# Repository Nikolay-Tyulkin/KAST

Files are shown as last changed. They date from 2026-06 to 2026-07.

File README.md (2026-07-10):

# KAST

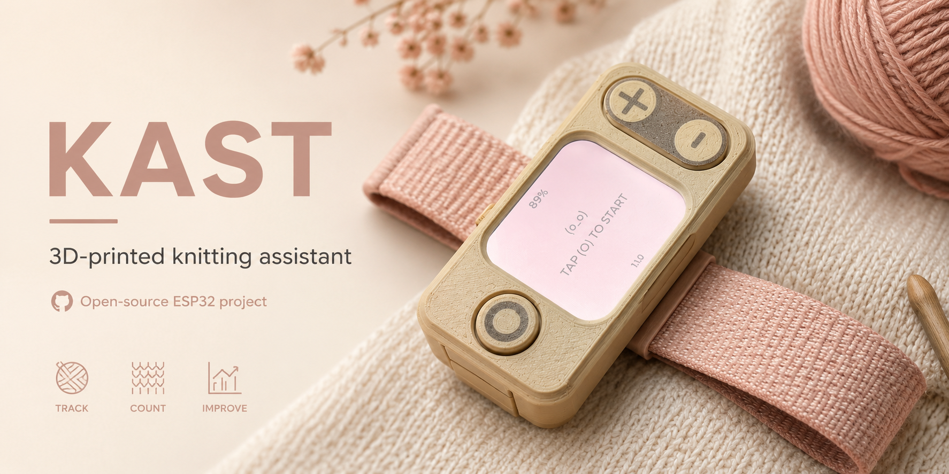
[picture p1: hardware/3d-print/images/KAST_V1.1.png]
KAST render


KAST is a portable knitting assistant based on the
`Waveshare ESP32-S3-LCD-1.69` board. The device counts rows, shows battery
charge as a percentage, and is controlled by three external buttons.

## Status

The repository currently contains an ESP-IDF MVP firmware:

- row counting with `+` and `-` buttons;
- Wi-Fi settings portal for boot beep, screen brightness, and screen sleep;
- a universal button for start, pause, resume, reset, and secondary actions;
- confirmed row reset flow;
- a display with a large row counter, session status, battery percentage, and firmware version;
- session, statistics, and history persistence in NVS;
- enclosure, 22 mm strap attachment, assembly, and 3D printing materials in `hardware/`.

The project is built with ESP-IDF CLI. Arduino and PlatformIO are not used.

## Video Demonstration

KAST Demonstration (https://www.youtube.com/shorts/3yuL7Apywl4)

## Quick Start

Open PowerShell 5.1 in the project root and activate the ESP-IDF profile:

```powershell
. "C:\Espressif\tools\Microsoft.v6.0.1.PowerShell_profile.ps1"
```

Build the firmware:

```powershell
idf.py build
```

Flash the current board on `COM14`:

```powershell
idf.py -p COM14 build flash
```

Open the device monitor:

```powershell
idf.py -p COM14 monitor
```

Exit the monitor with `Ctrl+]`.

## Firmware Version

The version is set in the root [`CMakeLists.txt`](CMakeLists.txt) through
`PROJECT_VER`, for example:

```cmake
set(PROJECT_VER "0.0.1-dev.37")
```

This value is passed into the firmware as `APP_VERSION`, shown at the bottom of
the screen, and included in ESP-IDF `Application information`. Before flashing a
working board, increment the dev counter by `1` so the running build is visible
on the screen.

## Controls

The confirmed external buttons are connected between GPIO and `GND`; pressed
state is active low (`0`).

| Button | GPIO | Purpose |
| --- | --- | --- |
| `+` | `GPIO2` | Add one row |
| `-` | `GPIO16` | Remove one row |
| Universal | `GPIO17` | Start, pause, resume, reset, and secondary actions |

Row reset sequence: `3` short presses of the universal button, then `1` long
press within a `2 s` window, then confirmation with one short press within
`5 s`.

Hold `+` for `3 s` in the main screen to toggle the settings Wi-Fi AP. When AP
is enabled, the device screen shows `SETTINGS` and a QR code for joining the
settings Wi-Fi network.

## Settings Portal

The device can expose a local Wi-Fi settings page without an external router.

- AP SSID: `KAST Settings`.
- Manual URL: `http://192.168.4.1`.
- The device settings screen shows a QR code for connecting to the settings AP.
- Captive portal DNS tries to open the settings page automatically after joining
  the AP; if the OS does not open it, use the manual URL.
- Settings are applied after `Save` and persisted in NVS.
- Available settings: boot beep on/off, screen brightness `0..100`, screen sleep
  on/off, and time until screen dimming.
- Current rows are saved after every row change and restored after power off/on.

## Hardware

Key board and wiring facts:

- board: `Waveshare ESP32-S3-LCD-1.69`;
- LCD: `SCLK=GPIO6`, `MOSI=GPIO7`, `RST=GPIO8`, `DC=GPIO4`, `CS=GPIO5`, `BL=GPIO15`;
- power latch: `SYS_OUT=GPIO40`, `SYS_EN=GPIO41`;
- battery ADC: `GPIO1`, which is `ADC_UNIT_1` / `ADC_CHANNEL_0` in ESP-IDF;
- battery divider: `R3=200k`, `R7=100k`, voltage multiplier `3`;
- primary strap: standard 22 mm purchased band with a 3D-printed holder.

Hardware documentation:

| Document | Contents |
| --- | --- |
| [`hardware/README.md`](hardware/README.md) | Hardware section index |
| [`hardware/BOM.md`](hardware/BOM.md) | Bill of materials |
| [`hardware/ASSEMBLY.md`](hardware/ASSEMBLY.md) | Assembly and smoke check |
| [`hardware/REVISIONS.md`](hardware/REVISIONS.md) | Hardware revision log |
| [`hardware/3d-print/README.md`](hardware/3d-print/README.md) | Enclosure, 3D printing, and model files |
| [Thingiverse](https://www.thingiverse.com/thing:7372245) | 3D-printable enclosure on Thingiverse |

## Project Structure

| Path | Purpose |
| --- | --- |
| [`main/main.c`](main/main.c) | Main firmware logic and UI |
| [`main/idf_component.yml`](main/idf_component.yml) | ESP-IDF managed dependencies |
| [`sdkconfig.defaults`](sdkconfig.defaults) | Base ESP-IDF settings |
| [`PROJECT_SPEC.md`](PROJECT_SPEC.md) | Product specification |
| [`IMPLEMENTATION_PLAN.md`](IMPLEMENTATION_PLAN.md) | Implementation plan |
| [`ACCEPTANCE_CRITERIA.md`](ACCEPTANCE_CRITERIA.md) | Acceptance criteria |
| [`hardware/`](hardware/README.md) | Hardware, enclosure, and assembly |

## Verification After Changes

Minimal local firmware check:

```powershell
idf.py build
```

After flashing the device, verify:

- the screen turns on;
- the expected `0.0.1-dev.N` version is visible at the bottom;
- `+` and `-` change the row counter;
- the battery is displayed as a percentage.

For battery diagnostics, look for monitor lines in this format:

```text
Battery ADC raw=... adc_mv=... bat_mv=... pct=...
```

## Development Notes

- ESP-IDF target: `esp32s3`.
- UI and logic term: `rows`.
- Activate the ESP-IDF PowerShell profile with the dot-sourcing command from
  "Quick Start".
- `source ...` does not activate the profile in the current PowerShell 5.1
  session.

## License

- Firmware and repository documentation: [`MIT License`](LICENSE).
- 3D printed parts, CAD files, and physical-design assets:
  [`CC BY-NC 4.0`](hardware/3d-print/LICENSE.md).

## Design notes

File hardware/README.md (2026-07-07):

# Hardware

This section contains the physical-device materials for KAST: enclosure files,
3D-printing assets, assembly photos, strap options, and component notes.

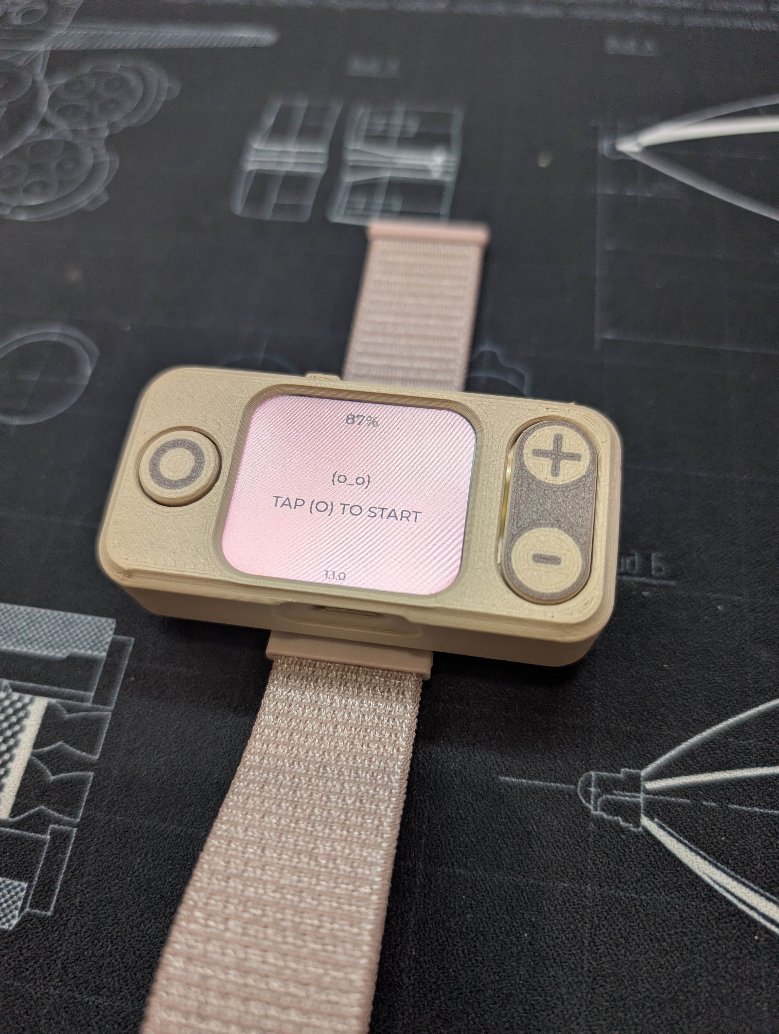
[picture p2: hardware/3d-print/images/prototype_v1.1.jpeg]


## Sections

| Path | Purpose |
| --- | --- |
| [`3d-print/`](3d-print/README.md) | Enclosure files, print settings, and assembly-oriented 3D-print notes |
| [`3d-print/source/`](3d-print/source/README.md) | Source STEP files for the assembly, enclosure, and components |
| [`BOM.md`](BOM.md) | Bill of materials for the build |
| [`ASSEMBLY.md`](ASSEMBLY.md) | Assembly steps and smoke check |
| [`REVISIONS.md`](REVISIONS.md) | Hardware revision log |
| [`3d-print/LICENSE.md`](3d-print/LICENSE.md) | License for 3D printed parts and CAD files |

## Target Device

- Board: `Waveshare ESP32-S3-LCD-1.69`
- Screen: integrated board LCD
- Controls: 3 external buttons
- Power: battery connected to the board
- Strap: standard 22 mm purchased band
- Main use case: row counting while knitting

## License

The 3D printed parts, CAD files, and physical-design assets are licensed under
[`CC BY-NC 4.0`](3d-print/LICENSE.md).

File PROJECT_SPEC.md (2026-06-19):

# PROJECT_SPEC: KAST

## 1. Product Goal

KAST is a standalone knitting assistant based on the
`Waveshare ESP32-S3-LCD-1.69` board. It helps the user count rows reliably
during knitting, control the current session, and see battery state.

The MVP goal is to replace a manual row counter with a simple gift-ready device
that requires no training, runs from battery power, and keeps local history for
completed sessions.

Core value:

- the user sees a large current row count;
- the user can quickly add or remove one row with physical buttons;
- the user can start, pause, finish, and inspect basic statistics;
- the device warns about low battery;
- on shutdown, the current session is closed and saved to history.

## 2. MVP Scope

Included in MVP:

- display current row count;
- manual row counter control with `+` and `-` buttons;
- universal button for session control, reset confirmation, and statistics;
- built-in board power button for power on/off;
- confirmation before row reset;
- battery percentage display;
- low-battery warning;
- current session timer in `hh:mm:ss`;
- current session status display;
- firmware version shown at the bottom of the screen;
- current session closure on shutdown or finish;
- completed session storage in local NVS history;
- firmware for `Waveshare ESP32-S3-LCD-1.69` built with ESP-IDF.

The MVP is designed around one current active session. After power-on, a new
session does not start automatically; the user must explicitly start it with the
universal button.

Out of scope for MVP:

- BLE, Wi-Fi, mobile app, web UI, cloud sync, OTA updates;
- project lists, user profiles, pattern templates, complex analytics;
- automatic row detection without a button press;
- multiple independent row counters;
- Arduino and PlatformIO builds.

## 3. Target Users

Primary user:

- a person who knits by hand and wants to avoid losing row count;
- a non-technical user;
- a user who may receive the device as a gift and expects understandable
  behavior without setup.

Secondary users:

- the gift giver, who wants a ready-to-use device;
- the developer or assembler, who flashes and checks the device before handoff.

UX requirements:

- minimal modes;
- large digits;
- clear physical actions;
- protection from accidental reset;
- no phone or computer required for normal use.

## 4. User Scenarios

### 4.1 Power On

1. The user presses the board power button.
2. The device turns on and holds power through the latch.
3. The screen shows the no-active-session state.
4. Battery percentage is visible in the top-right area.
5. Firmware version is visible at the bottom.

Expected result: the user understands that the device is ready, but no session
has started yet.

### 4.2 Start New Session

1. The user short-presses the universal button.
2. The device creates a new session.
3. Row count is set to `0`.
4. Session timer starts from `00:00:00`.
5. Status changes to active.

Expected result: the user can start knitting and count rows.

### 4.3 Add Row

1. The user completes a knitting row.
2. The user presses `+`.
3. Row count increases by `1`.
4. The updated number is shown immediately in the center of the screen.

Expected result: each completed row is recorded with one press.

### 4.4 Correct Counting Error

1. The user notices that one extra row was counted.
2. The user presses `-`.
3. If row count is greater than `0`, it decreases by `1`.
4. If row count is `0`, it remains `0`.

Expected result: the user can correct mistakes without creating negative values.

### 4.5 Pause and Resume

1. During an active session, the user short-presses the universal button.
2. The device pauses the session.
3. The clean session timer stops.
4. The screen shows paused status.
5. Another short universal-button press resumes the session.

Expected result: break time is not included in active knitting duration.

### 4.6 Reset Rows With Confirmation

1. The user initiates reset with `3` short universal-button presses followed by
   `1` long universal-button press within a `2 s` window.
2. The device shows a reset confirmation prompt.
3. The device waits up to `5 s` for confirmation.
4. The user confirms with one short universal-button press.
5. Row count becomes `0`.
6. If confirmation does not happen within `5 s`, reset is canceled.

Expected result: accidental presses do not erase the current row count.

### 4.7 Finish Session

1. The user finishes the current knitting work.
2. The user performs one long universal-button press.
3. The device saves the session to history.
4. The saved record includes start time, end time, duration, and final row count
   where available.
5. The screen returns to no-active-session state.

Expected result: current work is saved to history and the next session starts
separately.

### 4.8 Power Off

1. The user turns off the device with the board power button.
2. If a session is active or paused, the device closes and saves it.
3. The device drops the power latch.

Expected result: the closed session does not resume automatically on next
power-on.

### 4.9 View Statistics

1. The user holds `-` and the universal button together.
2. The device shows basic data from the last session and/or history.
3. The user can return to the main screen.

Expected result: the user can inspect previous work without external devices.

## 5. Functional Requirements

### 5.1 Display

- FR-001. The display shows the current row count as the most prominent element.
- FR-002. Battery percentage is visible in the top-right area.
- FR-003. The session timer is shown in `hh:mm:ss`.
- FR-004. The current status is visible: no session, active, paused, reset
  confirmation, low battery, or saved.
- FR-005. Firmware version is visible at the bottom of the screen.
- FR-006. The UI must remain readable on the `240x280` display.

### 5.2 Row Counter

- FR-010. In an active session, `+` increments row count by `1`.
- FR-011. In an active session, `-` decrements row count by `1`.
- FR-012. Row count never goes below `0`.
- FR-013. Row count changes are shown within `200 ms` after a valid press.
- FR-014. `+` and `-` do not change rows while the session is paused.
- FR-015. Without an active session, `+` and `-` do not change rows, except for
  valid statistics combinations.

### 5.3 Session Management

- FR-020. A short universal-button press starts a session when no session is
  active.
- FR-021. A short universal-button press pauses an active session.
- FR-022. A short universal-button press resumes a paused session.
- FR-023. A long universal-button press (`1.5 s`) finishes an active or paused
  session and saves it.
- FR-024. A session has a clean active timer that excludes pause time.
- FR-025. Only one session can be active at a time.

### 5.4 Row Reset

- FR-030. Reset requires `3` short universal-button presses followed by `1` long
  press within a `2 s` window.
- FR-031. Reset opens a confirmation prompt.
- FR-032. Confirmation requires one short universal-button press within `5 s`.
- FR-033. Unconfirmed reset is canceled and row count remains unchanged.

### 5.5 Battery and Power

- FR-040. Battery is measured through `GPIO1` / `ADC_CHANNEL_0`.
- FR-041. Battery voltage is calculated from ADC voltage using multiplier `3`.
- FR-042. Battery percentage is displayed.
- FR-043. `pct < 15` shows a low-battery warning.
- FR-044. On normal power-off, an active or paused session is saved before
  `SYS_EN` is set to `0`.

### 5.6 History and Statistics

- FR-050. Completed sessions are stored locally in NVS.
- FR-051. MVP history stores the latest `20` completed sessions.
- FR-052. Statistics show last session, total rows, and total clean time.
- FR-053. History write happens on finish or normal shutdown, not on every row.
- FR-054. Empty or unreadable history does not block device startup.

### 5.7 Firmware Version

- FR-060. Firmware version is set with `PROJECT_VER` in the root
  `CMakeLists.txt`.
- FR-061. Version format is `0.0.1-dev.N`.
- FR-062. `PROJECT_VER` is passed to the firmware as `APP_VERSION`.
- FR-063. The version is visible on screen and in ESP-IDF application metadata.

## 6. Non-Functional Requirements

- NFR-001. Firmware builds with ESP-IDF CLI using `idf.py build`.
- NFR-002. Target is `esp32s3`.
- NFR-003. Normal flashing uses `idf.py -p COM14 build flash`.
- NFR-004. The device works without network connectivity.
- NFR-005. The UI is readable on the built-in round-corner LCD.
- NFR-006. Button handling includes debounce.
- NFR-007. Storage writes are limited to avoid unnecessary flash wear.
- NFR-008. Battery readings are diagnostic-friendly through monitor logs.
- NFR-009. Documentation covers buttons, build, flashing, and basic diagnostics.

## 7. Data Model

### 7.1 Session

Fields:

- `id` - session identifier;
- `state` - none, active, paused, finished;
- `rows_count` - current or final row count;
- `started_at` - session start timestamp or uptime;
- `ended_at` - finish timestamp or uptime;
- `active_duration_sec` - clean active duration excluding pause time;
- `pause_started_at` - current pause start time, if paused;
- `close_reason` - `finished`, `power_off`, or equivalent.

### 7.2 SessionHistory

Fields:

- `sessions` - saved session list;
- `max_sessions` - maximum saved sessions in MVP (`20`);
- `last_session_id` - reference to the latest completed session.

### 7.3 BatteryState

Fields:

- `raw_adc` - raw ADC value;
- `adc_mv` - voltage at the ADC pin;
- `battery_mv` - calculated battery voltage;
- `percent` - calculated charge percentage;
- `is_low` - low-battery flag;
- `updated_at` - last measurement time.

### 7.4 DeviceState

Fields:

- `firmware_version` - firmware version;
- `power_state` - on or shutting down;
- `screen_state` - main, reset confirmation, statistics, warning;
- `active_session_id` - current session if present.

### 7.5 InputEvent

Fields:

- `button` - `plus`, `minus`, `universal`, `power`;
- `event_type` - short press, long press, sequence, combination;
- `timestamp` - event time;
- `handled` - handled or rejected.

## 8. Technical Stack

Platform:

- `Waveshare ESP32-S3-LCD-1.69`;
- `ESP32-S3` microcontroller;
- `240x280` ST7789 LCD;
- physical `+`, `-`, universal, and board power buttons;
- battery measurement through `BAT_ADC` on `GPIO1`.

Firmware:

- ESP-IDF CLI;
- target `esp32s3`;
- C;
- FreeRTOS;
- LVGL through `esp_lvgl_port`;
- `esp_lcd` for display;
- `adc_oneshot` for battery;
- NVS for local history.

Confirmed local environment:

- ESP-IDF `v6.0.1`;
- `IDF_PATH`: `C:\esp\v6.0.1\esp-idf`;
- `IDF_TOOLS_PATH`: `C:\Espressif\tools`;
- PowerShell profile:
  `. "C:\Espressif\tools\Microsoft.v6.0.1.PowerShell_profile.ps1"`.

Commands:

- build: `idf.py build`;
- flash current board: `idf.py -p COM14 build flash`;
- monitor: `idf.py -p COM14 monitor`;
- exit monitor: `Ctrl+]`.

Battery:

- `BAT_ADC` is connected to `GPIO1`;
- ESP-IDF channel for ESP32-S3 is `ADC_CHANNEL_0`;
- divider is `R3=200k`, `R7=100k`;
- battery voltage multiplier is `3`.

## 9. Risks and Open Questions

### 9.1 Risks

- R-001. The universal button can become overloaded if too many gestures are
  added.
- R-002. Users may accidentally finish a session if long-press behavior is not
  obvious.
- R-003. Battery percentage may be approximate without calibration.
- R-004. Frequent flash writes can wear NVS if row changes are persisted too
  often.
- R-005. Small text or poor color settings can hurt readability.
- R-006. Sudden power loss can lose an active session if no checkpoint exists.
- R-007. Gift-device use requires very simple behavior; complex modes reduce
  clarity.

### 9.2 Open Questions

- Q-001. Should long-press finish require an additional confirmation?
- Q-002. Is `1.5 s` the final long-press threshold?
- Q-003. Is `15%` the final low-battery threshold?
- Q-004. Should session duration exclude all pause time? MVP says yes.
- Q-005. Is `20` completed sessions enough for MVP history?
- Q-006. Should statistics show only the last session or aggregated totals too?
- Q-007. Should row changes be allowed while paused? MVP says no.
- Q-008. What exact text should appear on the no-active-session screen?

## 10. MVP Acceptance Criteria

- AC-001. Firmware version is displayed in `0.0.1-dev.N` format.
- AC-002. After power-on, no session starts automatically.
- AC-003. The user can start a session with one short universal-button press.
- AC-004. In an active session, `+` increments rows by `1`.
- AC-005. In an active session, `-` decrements rows by `1`, but not below `0`.
- AC-006. Row count is displayed large in the center of the screen.
- AC-007. Battery is displayed as a percentage in the top-right area.
- AC-008. Session timer is displayed in `hh:mm:ss`.
- AC-009. Reset requires the specified sequence and confirmation.
- AC-010. Finishing a session saves it to history.
- AC-011. Statistics can be opened with `-` plus universal button.
- AC-012. Normal shutdown saves an active or paused session.
- AC-013. A closed session does not resume automatically after power-on.
- AC-014. Low battery shows a warning.
- AC-015. Firmware builds with `idf.py build`.
- AC-016. Firmware flashes with `idf.py -p COM14 build flash`.
- AC-017. Documentation explains buttons, build, flashing, and diagnostics.

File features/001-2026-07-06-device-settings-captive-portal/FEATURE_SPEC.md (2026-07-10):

# Feature Spec: Device Settings Captive Portal

## Goal

Add a local settings web page to KAST, served by the device through its own Wi-Fi access point, and keep the current row session after power off and power on.

## Context And Problem

KAST needs basic user-adjustable settings without reflashing firmware. The settings must be reachable without an external router or internet connection.

The current knitting session must also survive power loss. Losing the current row count is a critical failure during knitting, so the current rows must be persisted as the user works.

## Target Users

- A knitter who uses KAST during a project and wants to adjust basic device behavior.
- A developer or tester who needs quick access to settings without rebuilding firmware.

## User Scenarios

- From the main screen, the user holds `+` for `3 s`; the device enables its Wi-Fi access point and opens the settings screen.
- The settings screen uses the pause color scheme, shows `SETTINGS`, and shows a Wi-Fi QR code.
- The user joins the `KAST Settings` Wi-Fi AP. The OS may open the captive portal automatically.
- If the captive portal does not open, the user opens `http://192.168.4.1` manually from documentation or known fallback behavior.
- The user changes settings on the web page and presses `Save`; the device applies and persists the settings.
- The user holds `+` for `3 s` again from the main/settings state; the device disables the Wi-Fi AP.
- The user changes rows with `+` or `-`, powers the device off, powers it on again, and the row session continues from the last saved value.

## Functional Requirements

- The device must toggle Wi-Fi AP mode with a `3 s` long press on `+` from the main screen.
- The AP toggle must be reversible: long `+` turns AP on when it is off and turns AP off when it is on.
- The AP SSID is `KAST Settings`.
- The settings page must be available through captive portal behavior after joining the AP.
- If the captive portal does not open automatically, the settings page must be available at `http://192.168.4.1`.
- The settings screen on the device must use the same color scheme as pause.
- The settings screen on the device must show the English title `SETTINGS`.
- The settings screen must show a QR code for joining the `KAST Settings` Wi-Fi AP.
- The settings screen must not show manual Wi-Fi connection text in place of the QR code.
- The settings screen content must not overlap the battery percentage.
- The web settings page must be in English.
- The web settings page must contain a boot beep on/off setting.
- Boot beep controls only the startup melody, not all possible device sounds.
- The web settings page must contain screen brightness from `0` to `100`.
- The default brightness must be `50`.
- The web settings page must contain screen sleep on/off.
- Screen sleep means dimming the display to save battery, not shutting down the device or ending the row session.
- The web settings page must contain a screen sleep timeout in seconds.
- Settings must apply and persist only after pressing `Save`.
- Saved settings must survive reboot and power off/on.
- The current row session must be saved after every row change.
- After power off/on, the device must restore the last saved row count and session state.
- Existing UI and logic terminology must use `rows`.

## Non-Functional Requirements

- The web page must be simple enough for ESP32-S3 resources.
- Settings must work without internet and without an external router.
- Enabling AP must not break the row counter.
- Row persistence after every change must be reliable while considering NVS flash wear.
- The settings page must be readable on a mobile phone.
- Firmware must use ESP-IDF, not Arduino or PlatformIO.

## Out Of Scope

- Connecting KAST to a home Wi-Fi router in station mode.
- User accounts, admin passwords, or authentication.
- Firmware update through the web page.
- Configuring all future sounds; only boot beep is in scope.
- Changing hardware pins or adding new sound hardware.
- Syncing history with external services.

## Dependencies And Constraints

- Project target: ESP-IDF on `esp32s3`.
- Board: `Waveshare ESP32-S3-LCD-1.69`.
- `+` button: `GPIO2`, active level `0`.
- Current firmware already uses NVS for history and now also uses it for settings and current session state.
- Captive portal behavior requires DNS interception and an HTTP server on the device.
- Wi-Fi AP increases power consumption and can conflict with screen sleep UX.
- Current LVGL fonts do not include Cyrillic glyphs, so the device settings screen uses English text.

## Open Questions

- Should the AP be open forever, or should it get an optional password later?
- Should AP automatically stop after an inactivity timeout?
- Should screen sleep be disabled while AP is enabled so the QR code remains visible?
- Should the first button press after screen dimming only wake the screen, or also perform the button action?
- Should row persistence use a wear-aware log format if the device is used heavily for long sessions?

## Risks And Assumptions

- Assumption: the web page is served directly by the device in AP mode.
- Assumption: the manual settings URL remains `http://192.168.4.1`.
- Risk: captive portal behavior is OS-specific and automatic opening cannot be guaranteed on every phone or desktop OS.
- Risk: saving rows after every change increases flash writes; future wear-aware storage may be needed.
- Risk: enabled AP increases battery drain.
- Risk: if screen sleep dims while AP is on, the user may not see the QR code until waking the screen.

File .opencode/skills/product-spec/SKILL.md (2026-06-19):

---
name: product-spec
description: Use when preparing or refining requirements for the knitting device: buttons, rows, screen, battery, board constraints, and acceptance criteria.
license: MIT
compatibility: opencode
metadata:
  project: knitting-assistant
  purpose: requirements
---

## What to Do

Prepare a technical product specification before implementation starts.

## Required Output

Include sections for:

- product goal;
- target users;
- MVP scope;
- out-of-scope items;
- user scenarios during knitting;
- functional requirements;
- non-functional requirements;
- acceptance criteria;
- open questions;
- risks and assumptions.

## Rules

- Do not create application code when using this skill.
- Ask clarifying questions if the product goal or MVP scope is unclear.
- Make requirements concrete and verifiable.
- Mark assumptions explicitly.
- Use the term `rows`; do not replace it with `levels` unless the user
  explicitly asks for that terminology.

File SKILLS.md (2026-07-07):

# SKILLS

Project skill index for `knitting_assistant`.

Important: opencode loads skills from `.opencode/skills/<name>/SKILL.md`, not
from this file.

## Active Skills

- `product-spec` (`.opencode/skills/product-spec/SKILL.md`) - use when device
  requirements must be captured: buttons, rows, screen, battery, and board
  constraints.
- `implementation-plan` (`.opencode/skills/implementation-plan/SKILL.md`) - use
  when agreed requirements must be broken down into embedded implementation
  stages.
- `quality-gate` (`.opencode/skills/quality-gate/SKILL.md`) - use before a
  final answer for implementation tasks: what was checked, what was not checked,
  and what risks remain.
- `feature-artifacts` (`.opencode/skills/feature-artifacts/SKILL.md`) - use when
  preparing English product feature artifacts before implementation: feature
  spec, implementation plan, and acceptance criteria.
- `release-notes-github` (`.opencode/skills/release-notes-github/SKILL.md`) -
  use when drafting English GitHub release notes for KAST releases from a source
  tag to a target tag.

## Mini Rules

- Do not write code during `product-spec` or `implementation-plan` work unless
  the user explicitly asks to move into implementation.
- Use the term `rows` for UI and logic.
- Before the final answer for implementation work, use `quality-gate`: review
  changes, run available checks, and explicitly state unchecked areas.
- Confirmed firmware check: activate the ESP-IDF profile with
  `. "C:\Espressif\tools\Microsoft.v6.0.1.PowerShell_profile.ps1"`, then run
  `idf.py build`.
- Confirmed board flash command: `idf.py -p COM14 build flash`, unless the user
  specifies another port.
- Before assistant-performed flashing, increment `PROJECT_VER` in the root
  `CMakeLists.txt` to the next SemVer dev build; the version must be shown at
  the bottom of the screen after flashing.
- Battery mapping: Waveshare `GPIO1/BAT_ADC` maps to ESP-IDF `ADC_CHANNEL_0` on
  ESP32-S3; voltage divider is `200k/100k`, multiplier `3`.
- For logs and smoke checks, use `idf.py -p COM14 monitor`; exit with `Ctrl+]`.
- There are no separate tests or linters currently; do not invent commands
  until matching configs exist.
- During `feature-artifacts` work, do not change application code; create only
  English documentation under `features/NNN-YYYY-MM-DD-feature-slug/`.

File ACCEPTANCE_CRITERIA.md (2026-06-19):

# ACCEPTANCE_CRITERIA: KAST

## 1. MVP Definition of Done

The MVP is complete when all conditions below are met:

- firmware builds with ESP-IDF using `idf.py build` after activating the
  ESP-IDF PowerShell profile;
- firmware flashes successfully to `Waveshare ESP32-S3-LCD-1.69` with
  `idf.py -p COM14 build flash`, unless another port is specified;
- firmware version uses `0.0.1-dev.N`, is visible at the bottom of the screen,
  and appears in ESP-IDF `Application information`;
- after power-on, the device shows a no-active-session state and does not start
  a session automatically;
- the user can start one new session with a short universal-button press;
- in an active session, `+` increases row count by `1`;
- in an active session, `-` decreases row count by `1`, but not below `0`;
- row changes are visible on screen no later than `200 ms` after a valid press;
- pause stops the clean session timer, and another short universal-button press
  resumes the session;
- while paused, `+` and `-` do not change row count;
- a `1.5 s` long universal-button press finishes an active or paused session
  and saves it to history;
- row reset requires `3` short universal-button presses and `1` long press
  within `2 s`, then confirmation with one short press within `5 s`;
- unconfirmed reset is canceled after `5 s` without changing row count;
- statistics open by holding `-` and universal together;
- history stores the latest `20` completed sessions locally;
- statistics show last session, total rows, and total clean time;
- normal shutdown closes and saves an active or paused session before power is
  dropped;
- after power-on, a closed session does not resume automatically;
- battery is shown as a percentage in the top-right area;
- when charge is below `15%`, the user sees a low-battery warning;
- monitor logs allow checking firmware version and battery diagnostics in the
  format `Battery ADC raw=... adc_mv=... bat_mv=... pct=...`;
- UI uses the term `rows` and keeps the row count as the dominant central
  element;
- the device works without BLE, Wi-Fi, phone, cloud, Arduino, or PlatformIO;
- documentation describes buttons, screens, build, flashing, and basic
  diagnostics.

## 2. User Acceptance Scenarios

### AC-U01. Power On

Preconditions:

- board is flashed with the current MVP firmware;
- battery is connected or power is supplied normally.

Steps:

1. Press the board power button.
2. Wait for the screen to turn on.

Expected result:

- the device holds power;
- the no-active-session screen is shown;
- a new session does not start automatically;
- battery percentage is visible in the top-right area;
- firmware version `0.0.1-dev.N` is visible at the bottom.

### AC-U02. Start New Session

Precondition:

- the device is on the no-active-session screen.

Steps:

1. Short-press the universal button.

Expected result:

- a new session is created;
- row count is `0`;
- timer shows `00:00:00` and starts counting;
- status shows active session.

### AC-U03. Add Rows

Precondition:

- active session is running.

Steps:

1. Press `+` once.
2. Press `+` two more times.

Expected result:

- after the first press, `1` row is displayed;
- after three presses, `3` rows are displayed;
- each valid press creates exactly one increment;
- screen updates within `200 ms` after the press.

### AC-U04. Remove Rows and Lower Bound

Preconditions:

- active session is running;
- row count is `1`.

Steps:

1. Press `-` once.
2. Press `-` again.

Expected result:

- after the first press, `0` rows are displayed;
- after the second press, the value remains `0`;
- negative values never appear.

### AC-U05. Pause and Resume

Preconditions:

- active session is running;
- timer is greater than `00:00:00`.

Steps:

1. Short-press the universal button.
2. Wait a few seconds.
3. Press `+` and `-` while paused.
4. Short-press the universal button again.

Expected result:

- status changes to paused after the first press;
- clean timer does not increase while paused;
- `+` and `-` do not change row count while paused;
- second short press resumes the session;
- timer counts active time again after resume.

### AC-U06. Reset Rows With Confirmation

Preconditions:

- active session is running;
- row count is greater than `0`.

Steps:

1. Perform `3` short universal-button presses.
2. Perform `1` long universal-button press within the `2 s` window.
3. Wait for the reset confirmation screen.
4. Short-press the universal button within `5 s`.

Expected result:

- the device shows reset confirmation;
- after confirmation, row count becomes `0`;
- the session remains current unless it is separately finished.

### AC-U07. Cancel Reset by Timeout

Preconditions:

- active session is running;
- row count is greater than `0`;
- reset confirmation screen is open.

Steps:

1. Do not press the universal button for `5 s`.

Expected result:

- reset confirmation closes;
- row count remains unchanged;
- the device returns to the previous session screen.

### AC-U08. Finish Session

Preconditions:

- active or paused session is running;
- row count is greater than `0`.

Steps:

1. Perform one `1.5 s` long universal-button press.

Expected result:

- session finishes immediately;
- session is saved to history;
- final rows and clean duration are saved;
- screen returns to no-active-session state or shows a short saved status.

### AC-U09. View Statistics

Precondition:

- history contains at least one completed session.

Steps:

1. Hold `-` and universal together.

Expected result:

- statistics screen opens;
- last-session data is visible;
- total rows are visible;
- total clean time is visible;
- the user can return to the main screen without external devices.

### AC-U10. Normal Shutdown With Save

Preconditions:

- active or paused session is running;
- row count is greater than `0`.

Steps:

1. Turn off the device with the board power button.
2. Turn the device on again.
3. Open statistics.

Expected result:

- before power-off, the current session is closed with reason `power_off`;
- after power-on, the session does not resume automatically;
- the closed session is available in history or statistics.

### AC-U11. Battery and Low Charge

Preconditions:

- device is powered on;
- battery ADC is connected to `GPIO1`, using `ADC_CHANNEL_0` and divider
  multiplier `3`.

Steps:

1. Check battery percentage on screen.
2. Check battery monitor log.
3. Check `pct < 15` with a real low battery, temporary threshold, or mock mode.

Expected result:

- battery is shown as a percentage in the top-right area;
- monitor contains `raw`, `adc_mv`, `bat_mv`, and `pct`;
- when `pct < 15`, the screen shows a low-battery warning.

## 3. Software Criteria

### AC-S01. Build

Check commands:

```powershell
. "C:\Espressif\tools\Microsoft.v6.0.1.PowerShell_profile.ps1"
idf.py build
```

Expected result:

- build completes without errors;
- target remains `esp32s3`;
- build does not require Arduino or PlatformIO.

### AC-S02. Flash

Check commands:

```powershell
idf.py -p COM14 build flash
```

Before flashing, increment `PROJECT_VER` to the next `0.0.1-dev.N`.

Expected result:

- flashing succeeds;
- new version is visible on the screen;
- the same `App version` is visible in monitor.

### AC-S03. Diagnostic Logs

Check command:

```powershell
idf.py -p COM14 monitor
```

Expected result:

- monitor shows application start;
- monitor shows firmware version;
- monitor shows battery diagnostics;
- during button debugging, monitor can show events such as `PLUS_SHORT`,
  `MINUS_SHORT`, `UNIVERSAL_SHORT`, `UNIVERSAL_LONG`, `RESET_REQUEST`,
  `STATS_OPEN`, `POWER_LONG`, or equivalent messages.

### AC-S04. Buttons and Debounce

Expected result:

- one physical short press creates one user event;
- long press is detected after `1.5 s`;
- bounce does not increment or decrement rows multiple times;
- one long press alone does not count as reset sequence without the preceding
  three short presses.

### AC-S05. History Storage

Expected result:

- history is written on session finish or normal shutdown;
- history is not written on every row;
- history is limited to the latest `20` completed sessions;
- history read errors do not break startup: history is treated as empty and the
  error is logged.

### AC-S06. UI and Readability

Expected result:

- row count is the most prominent screen element;
- battery is top-right;
- firmware version is at the bottom;
- timer uses `hh:mm:ss`;
- statuses for no session, active, paused, reset confirmation, and low battery
  are distinguishable on the `240x280` screen.

## 4. Error and Empty-State Criteria

### AC-E01. No Active Session

Expected result:

- screen clearly shows that there is no active session;
- `+` does not change rows;
- `-` does not change rows except as part of the statistics combination;
- short universal-button press starts a new session.

### AC-E02. Rows Are Zero

Expected result:

- pressing `-` keeps the value at `0`;
- negative values never appear in UI, logs, or session model.

### AC-E03. Empty History

Expected result:

- statistics screen does not crash and does not show garbage data;
- the user sees a clear empty state;
- aggregate values are `0`.

### AC-E04. History Overflow

Expected result:

- after more than `20` completed sessions, the latest `20` are retained;
- statistics remain correct;
- device does not hang or corrupt NVS because history grows.

### AC-E05. Unconfirmed Reset

Expected result:

- if confirmation is not completed within `5 s`, rows are not reset;
- the device returns to the previous session state.

### AC-E06. Battery Error or Invalid ADC Reading

Expected result:

- application keeps running;
- monitor contains a diagnostic message;
- UI does not show invalid negative percentages or values above the allowed
  range without clamping;
- row counting and session control remain available.

### AC-E07. NVS Read Error

Expected result:

- device starts with empty history;
- error is logged;
- a new completed session can be saved if NVS writes are available.

### AC-E08. Fast or Accidental Presses

Expected result:

- accidental single universal-button press does not reset rows;
- accidental single long press finishes the session according to MVP rules and
  saves it to history;
- reset requires the full sequence plus confirmation.

## 5. Minimum Checks Before Final Agent Response

For firmware changes, the agent must perform or explicitly state why it did not
perform:

1. Review changed files and ensure unrelated user changes were not overwritten.
2. Activate the ESP-IDF PowerShell profile:
   `. "C:\Espressif\tools\Microsoft.v6.0.1.PowerShell_profile.ps1"`.
3. Run `idf.py build`.
4. If the user requested flashing, increment `PROJECT_VER` to the next
   `0.0.1-dev.N`.
5. If the user requested flashing, run `idf.py -p COM14 build flash`, unless
   another port is specified.
6. If device verification is needed, run `idf.py -p COM14 monitor` and exit with
   `Ctrl+]`.
7. Verify that the expected firmware version is visible on screen.
8. Verify the main smoke scenario: start session, `+`, `-`, pause, resume, reset
   with confirmation, finish, statistics.
9. Verify battery on screen and monitor log:
   `Battery ADC raw=... adc_mv=... bat_mv=... pct=...`.
10. In the final answer, list which checks were performed and which were not.

For documentation-only tasks:

1. Review created or changed documents.
2. Ensure terminology uses `rows`.
3. Do not build or flash unless firmware code changed or the user requested it.
4. State in the final answer that hardware checks were not run because only
   documentation changed.

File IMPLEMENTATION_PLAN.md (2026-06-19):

# IMPLEMENTATION_PLAN: KAST

## 1. Implementation Goal

Implement the KAST MVP firmware for the `Waveshare ESP32-S3-LCD-1.69` board
using ESP-IDF.

The MVP must provide:

- row counting with `+` and `-`;
- one current session controlled by the universal button;
- a no-active-session screen;
- a clean session timer that excludes pause time;
- local history for the latest `20` completed sessions;
- statistics: last session, total rows, total clean time;
- battery display in the top-right area;
- low-battery warning below `15%`;
- firmware version at the bottom of the screen;
- build and flash through ESP-IDF CLI.

This document defines implementation order. It does not require code to be
created while planning.

## 2. Target Project Structure

The current project has most MVP logic in `main/main.c`. A later cleanup can
split it into smaller modules under `main/`:

```text
knitting_assistant/
  CMakeLists.txt
  sdkconfig.defaults
  README.md
  PROJECT_SPEC.md
  IMPLEMENTATION_PLAN.md
  ACCEPTANCE_CRITERIA.md
  main/
    CMakeLists.txt
    main.c
    app_config.h
    board_pins.h
    board_power.c
    board_power.h
    battery.c
    battery.h
    buttons.c
    buttons.h
    display.c
    display.h
    session.c
    session.h
    storage.c
    storage.h
    time_utils.c
    time_utils.h
    idf_component.yml
```

Module responsibilities:

- `main.c` - initialization, application task, top-level event loop;
- `app_config.h` - timeouts, thresholds, history size, behavior constants;
- `board_pins.h` - GPIO, ADC channels, display pins, battery divider values;
- `board_power.*` - power latch, power button, shutdown flow;
- `battery.*` - ADC reading and conversion to `adc_mv`, `battery_mv`, percent,
  and low-battery state;
- `buttons.*` - debounce and short/long/sequence/combination detection;
- `display.*` - LCD/LVGL initialization, screens, UI updates;
- `session.*` - session state, row count, clean timer, state transitions;
- `storage.*` - NVS history and aggregate statistics;
- `time_utils.*` - `hh:mm:ss` formatting and time helpers.

Minimal alternative: if a full split is too large for the first pass, extract
`board_pins.h`, `buttons.*`, `session.*`, `display.*`, and `battery.*` first,
then move storage later.

## 3. GPIO, Schematics, and Wiring

### 3.1 Confirmed Board Pins

LCD ST7789:

- `LCD_SCLK = GPIO6`;
- `LCD_MOSI = GPIO7`;
- `LCD_RST = GPIO8`;
- `LCD_DC = GPIO4`;
- `LCD_CS = GPIO5`;
- `LCD_BL = GPIO15`.

Power latch:

- `SYS_OUT = GPIO40`;
- `SYS_EN = GPIO41`.

Battery:

- `BAT_ADC = GPIO1`;
- ESP-IDF on ESP32-S3 uses `ADC_UNIT_1`, `ADC_CHANNEL_0`;
- Waveshare divider: `R3=200k`, `R7=100k`;
- multiplier: `3`;
- formula: `battery_mv = adc_mv * 3`.

I2C on the board:

- `ESP32_SCL = GPIO10`;
- `ESP32_SDA = GPIO11`;
- used by RTC/IMU; do not reuse for buttons without an explicit decision.

Built-in power button:

- powers the board through hardware;
- after boot, `SYS_EN` must be held at `1`;
- `SYS_OUT` is used as input to read the power-button action;
- in MVP, the power button is for power on/off, not row counting.

### 3.2 Previous Temporary Button Pins

Earlier firmware used:

- `PIN_BTN_PLUS = GPIO0`;
- `PIN_BTN_MINUS = GPIO38`.

Risks:

- `GPIO0` is boot/strap related and can affect download mode;
- `GPIO38` is connected to `QMI_INT2` on the schematic and may conflict with
  the IMU;
- the universal button was not assigned to its final GPIO.

Conclusion: these pins are acceptable for early tests only. MVP uses the
confirmed external GPIOs.

### 3.3 Confirmed External Button Wiring

Each button is wired as:

```text
ESP32 GPIO ---- button ---- GND
```

GPIO settings:

- mode: input;
- pull: internal pull-up;
- active level: `0` when pressed;
- debounce: at least `30-50 ms`.

Confirmed assignments:

- `BTN_PLUS = GPIO2`;
- `BTN_MINUS = GPIO16`;
- `BTN_UNIVERSAL = GPIO17`.

Do not use these pins for external buttons without a separate decision:

- `GPIO0` - boot/strap;
- `GPIO1` - battery;
- `GPIO4/5/6/7/8/15` - LCD;
- `GPIO10/11` - I2C;
- `GPIO38` - `QMI_INT2`;
- `GPIO39` - `RTC_INT` on V2;
- `GPIO40/41` - power;
- `GPIO42` - buzzer on V2;
- `GPIO43/44` - UART/console;
- `GPIO45/46` - ESP32-S3 service/strap pins.

### 3.4 MVP Button Logic

`+` button:

- short press in active session: `rows_count += 1`;
- paused: row changes disabled;
- no active session: ignored or shows a start hint.

`-` button:

- short press in active session: `rows_count -= 1`, not below `0`;
- paused: row changes disabled;
- no active session: ignored except as part of the statistics combination.

Universal button:

- short press with no active session: start new session;
- short press in active session: pause;
- short press in paused session: resume;
- long press (`1.5 s`) in active or paused session: finish and save session;
- reset sequence: `3` short presses, then `1` long press within `2 s`;
- reset confirmation: one short press within `5 s`;
- statistics: hold `-` and universal together.

Built-in power button:

- powers the board on through hardware;
- during shutdown, active or paused session must be closed and saved;
- after saving, set `SYS_EN=0`.

## 4. Software Implementation Order

### Stage 0. Baseline Build and Versioning

Goal:

- ensure reproducible build, flash, and visible firmware version.

Files:

- `CMakeLists.txt`;
- `main/CMakeLists.txt`;
- `main/main.c`;
- `sdkconfig.defaults`;
- `README.md` if needed.

Tasks:

- ensure `PROJECT_VER` is set in the root `CMakeLists.txt`;
- pass `PROJECT_VER` into firmware as `APP_VERSION`;
- show version at the bottom of the screen;
- increment `0.0.1-dev.N` before every flash;
- keep `idf.py build` as the base check.

Minimal checks:

- activate ESP-IDF profile;
- run `idf.py build`;
- flash on request with `idf.py -p COM14 build flash`;
- verify `App version: 0.0.1-dev.N` in monitor or on screen.

Dependencies: none.

### Stage 1. Board and Config Layer

Goal:

- move GPIO and hardware constants out of business logic.

Files:

- `main/board_pins.h`;
- `main/app_config.h`;
- `main/main.c`;
- `main/CMakeLists.txt`.

Tasks:

- define LCD, power, battery, and button pins;
- define timeouts and thresholds:
  - debounce `30-50 ms`;
  - long press `1500 ms`;
  - reset sequence window `2000 ms`;
  - reset confirmation timeout `5000 ms`;
  - low battery threshold `15%`;
  - history size `20`;
- migrate button pins to `GPIO2`, `GPIO16`, `GPIO17`.

Checks:

- `idf.py build`;
- each button generates one clear event in monitor.

Dependencies: Stage 0.

### Stage 2. Battery Module

Goal:

- read battery voltage reliably and expose percentage and diagnostics.

Files:

- `main/battery.c`;
- `main/battery.h`;
- `main/board_pins.h`;
- `main/main.c`;
- `main/CMakeLists.txt`.

Tasks:

- configure ADC oneshot for `ADC_CHANNEL_0`;
- read raw ADC value;
- convert to `adc_mv`;
- calculate `battery_mv = adc_mv * 3`;
- map voltage to approximate percentage;
- set low-battery flag below `15%`;
- log `Battery ADC raw=... adc_mv=... bat_mv=... pct=...`.

Checks:

- `idf.py build`;
- monitor shows realistic `bat_mv` and percentage;
- UI shows battery at top-right.

Dependencies: Stage 1.

### Stage 3. Buttons and Input Events

Goal:

- provide stable input events independent from UI and session logic.

Files:

- `main/buttons.c`;
- `main/buttons.h`;
- `main/app_config.h`;
- `main/board_pins.h`;
- `main/main.c`.

Tasks:

- configure input GPIO with pull-ups;
- implement debounce;
- detect short and long press;
- detect reset sequence;
- detect `-` plus universal statistics combination;
- log events during debugging.

Checks:

- one physical short press creates one event;
- long press is detected after `1.5 s`;
- reset is not triggered by one long press alone.

Dependencies: Stage 1.

### Stage 4. Session Model and Row Counter

Goal:

- isolate session state transitions from UI.

Files:

- `main/session.c`;
- `main/session.h`;
- `main/time_utils.c`;
- `main/time_utils.h`;
- `main/main.c`.

Tasks:

- implement states: no session, active, paused, reset confirmation, statistics;
- implement start, pause, resume, finish;
- implement row increment/decrement with lower bound `0`;
- implement clean timer excluding pause time;
- implement reset confirmation behavior;
- create a completed-session record.

Checks:

- scenario transitions match acceptance criteria;
- `+/-` are disabled while paused;
- no active session starts automatically after boot.

Dependencies: Stage 3.

### Stage 5. UI and Screens

Goal:

- make the device readable and useful on the built-in screen.

Files:

- `main/display.c`;
- `main/display.h`;
- `main/main.c`;

Tasks:

- build main screen with large row count;
- show battery percentage at top-right;
- show timer and status;
- show firmware version at the bottom;
- show reset confirmation screen;
- show statistics screen;
- show low-battery state;
- keep text readable on `240x280`.

Checks:

- screen is readable on the real device;
- rows are the most prominent element;
- version is visible at the bottom.

Dependencies: Stages 2 and 4.

### Stage 6. Local History Storage

Goal:

- persist completed sessions and aggregate statistics in NVS.

Files:

- `main/storage.c`;
- `main/storage.h`;
- `main/session.c`;
- `main/main.c`;

Tasks:

- initialize NVS;
- store completed sessions on finish or normal shutdown;
- keep the latest `20` sessions;
- compute last session, total rows, total clean time;
- tolerate empty or unreadable history.

Checks:

- history survives reboot;
- more than `20` sessions keeps the latest `20`;
- NVS read errors do not block startup.

Dependencies: Stage 4.

### Stage 7. Normal Shutdown

Goal:

- save the current session before power is dropped.

Files:

- `main/board_power.c`;
- `main/board_power.h`;
- `main/session.c`;
- `main/storage.c`;
- `main/main.c`.

Tasks:

- read power-button action through `SYS_OUT`;
- close active or paused session with reason `power_off`;
- save session to NVS;
- set `SYS_EN=0` after saving.

Checks:

- active or paused session appears in history after power-cycle;
- closed session does not resume automatically.

Dependencies: Stage 6.

### Stage 8. Documentation and Final MVP Acceptance

Goal:

- align docs with actual firmware and hardware behavior.

Files:

- `README.md`;
- `PROJECT_SPEC.md`;
- `IMPLEMENTATION_PLAN.md`;
- `ACCEPTANCE_CRITERIA.md`;
- `hardware/`.

Tasks:

- document build, flash, monitor, and ESP-IDF profile activation;
- document button wiring and GPIOs;
- document reset sequence;
- document battery ADC mapping;
- document versioning workflow;
- run the acceptance smoke scenario on device when requested.

Checks:

- `idf.py build`;
- `idf.py -p COM14 build flash` when flashing is requested;
- `idf.py -p COM14 monitor` for logs;
- verify start, `+`, `-`, pause, reset confirmation, finish, statistics, and
  shutdown with saving.

Dependencies: all previous stages.

## 5. Stage Dependencies

Main order:

```text
Stage 0 -> Stage 1 -> Stage 2
                    -> Stage 3 -> Stage 4 -> Stage 5 -> Stage 6 -> Stage 7 -> Stage 8
```

Notes:

- battery can be implemented before complete button logic;
- UI can evolve in parallel with session state if a stable view model exists;
- history depends on the completed-session model;
- normal shutdown depends on storage;
- final docs depend on actual button behavior.

Critical blockers:

- final `board_pins.h` depends on confirmed `BTN_PLUS`, `BTN_MINUS`, and
  `BTN_UNIVERSAL` wiring;
- reset, statistics, and finish require stable button event handling;
- shutdown saving requires storage.

## 6. Minimum Checks by Stage

General checks:

- activate ESP-IDF profile:
  `. "C:\Espressif\tools\Microsoft.v6.0.1.PowerShell_profile.ps1"`;
- run `idf.py build`;
- before flashing, increment `PROJECT_VER` to the next `0.0.1-dev.N`;
- flash with `idf.py -p COM14 build flash`;
- monitor with `idf.py -p COM14 monitor`;
- exit monitor with `Ctrl+]`.

Stage smoke checks:

- Stage 0: version is visible in ESP-IDF `Application information` and at the
  bottom of the screen.
- Stage 1: build works after pin/config extraction.
- Stage 2: battery shows realistic `bat_mv` and percentage; monitor logs raw,
  ADC, battery voltage, and percentage.
- Stage 3: each press creates exactly one event; long press is detected after
  `1.5 s`.
- Stage 4: session state follows scenarios; `+/-` are disabled while paused.
- Stage 5: all screens are readable; rows are large and centered.
- Stage 6: history survives reboot and keeps the latest `20` sessions.
- Stage 7: shutdown closes and saves session before `SYS_EN=0`.
- Stage 8: full MVP acceptance passes on the device.

## 7. Risks and Mitigations

### R-001. Wrong GPIO Choice for External Buttons

Risk: chosen GPIO conflicts with boot, LCD, I2C, IMU, RTC, power, or UART.

Mitigation:

- keep all GPIOs in `board_pins.h`;
- do not use known reserved pins without explicit reason;
- verify selected GPIOs through pinout and monitor test before soldering;
- keep alternative candidates documented.

### R-002. Universal Button Complexity

Risk: short, long, sequence, and combination gestures become confusing.

Mitigation:

- log all button events during debugging;
- show clear confirmation prompts;
- make reset require the rare `3 short + long` sequence plus confirmation;
- keep statistics on a separate `- + universal` combination.

### R-003. Accidental Session Finish

Risk: the user holds the universal button too long and finishes a session.

Mitigation:

- save immediately after finish;
- show a saved status;
- consider undo later, but keep it out of MVP unless separately specified.

### R-004. Flash Wear From Frequent Writes

Risk: writing every row quickly wears NVS/flash.

Mitigation:

- save history only on finish or normal shutdown in MVP;
- keep intermediate state in RAM;
- add periodic checkpoints later only if needed.

### R-005. Active Session Loss on Sudden Power Loss

Risk: battery disconnect or power loss occurs before saving.

Mitigation:

- normal shutdown always follows `SYS_OUT -> save -> SYS_EN=0`;
- warn on low battery at `15%`;
- consider active-session checkpoints post-MVP if the risk becomes critical.

### R-006. Inaccurate Battery

Risk: ADC without calibration gives an approximate percentage.

Mitigation:

- use the correct `ADC_CHANNEL_0` for `GPIO1`;
- use divider multiplier `3`;
- log `raw`, `adc_mv`, `bat_mv`, `pct`;
- add ADC calibration or a discharge table later if needed.

### R-007. Screen Readability Issues

Risk: small text, color artifacts, or wrong RGB/BGR settings hurt UX.

Mitigation:

- use large fonts for rows;
- keep the main screen minimal;
- verify on the real display after UI changes;
- if artifacts remain, check `LV_COLOR_16_SWAP`, data endian, RGB/BGR, and
  ST7789 settings.

### R-008. Firmware Size Growth From LVGL Fonts

Risk: large fonts increase binary size.

Mitigation:

- include only used font sizes;
- do not include LVGL demos/examples unless needed;
- watch the app partition size after builds.

## 8. Decisions Still Requiring Confirmation

Hardware:

- confirm the final physical wiring for `+`, `-`, and universal buttons on each
  built device;
- confirm whether any temporary `GPIO0/GPIO38` references remain in code;
- document where button wires are routed in the current physical unit.

UI:

- confirm display language for firmware labels: English (`ROWS`, `PAUSE`) or
  another target language;
- decide whether the no-active-session screen shows last-session summary or
  only a start hint;
- decide whether low-battery warning is overlayed on all screens or shown as a
  status.

Storage:

- confirm that `20` sessions are enough without real calendar dates if RTC is
  not configured;
- decide whether history clearing is post-MVP.

## 9. Plan Readiness Criteria

Implementation can proceed after confirming:

- GPIOs for the three user buttons;
- UI language;
- no-active-session screen behavior;
- statistics screen format;
- time model: uptime seconds only or RTC-based timestamps.

If those decisions are not confirmed, implementation can still start with safe
stages:

- Stage 0;
- Stage 1;
- Stage 2;
- partial Stage 4 with C-level state logic independent of final GPIO.

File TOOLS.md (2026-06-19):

# TOOLS

Short tool reference for this repository.

## Default Tools

- For reading and editing files: built-in Codex/opencode file tools
  (`read`, `edit`, `apply_patch`).
- For commands: PowerShell. Run only commands that are actually supported by the
  repository.
- For searching: use `rg` before making assumptions about file structure.

## Current Project Constraints

- The project contains ESP-IDF firmware for `esp32s3`; use ESP-IDF CLI, not
  Arduino or PlatformIO.
- Confirmed check: `idf.py build`.
- There are no separate tests or linters currently; do not invent commands
  until matching configs exist.

## Confirmed Toolchain

- Working environment: `IDF PowerShell Environment`.
- `IDF_PATH`: `C:\esp\v6.0.1\esp-idf`
- `IDF_TOOLS_PATH`: `C:\Espressif\tools`
- `IDF_PYTHON_ENV_PATH`: `C:\Espressif\tools\python\v6.0.1\venv`
- ESP-IDF version: `v6.0.1`.

## Firmware Commands

- Main command: `idf.py`, for example `idf.py build`.
- Additional utilities: `esptool.py`, `espefuse.py`, `espsecure.py`,
  `otatool.py`, `parttool.py`.
- Before running commands in PowerShell 5.1, activate the ESP-IDF profile through
  dot-sourcing:
  `. "C:\Espressif\tools\Microsoft.v6.0.1.PowerShell_profile.ps1"`
- Do not use `source ...` in PowerShell 5.1. The command is not found and the
  profile is not activated.
- Before flashing, increment the `PROJECT_VER` dev counter in the root
  `CMakeLists.txt` by `1` in `0.0.1-dev.N` format so the new firmware is visible
  at the bottom of the screen and in ESP-IDF `Application information`.
- Build: `idf.py build`.
- Flash current board: `idf.py -p COM14 build flash`.
- Log monitor: `idf.py -p COM14 monitor`; exit with `Ctrl+]`.
- If the profile is not activated, do not run firmware commands blindly. Report
  that prerequisite clearly.

## Hardware and Domain Notes

- Target device: `Waveshare ESP32-S3-LCD-1.69` + battery + 3 buttons.
- Use the term `rows` in text, UI, and logic.
- Battery: Waveshare connects `BAT_ADC` to `GPIO1`; in ESP-IDF on ESP32-S3 use
  `ADC_CHANNEL_0`, voltage-divider multiplier `3` (`200k/100k`).
- Verification priorities: visible firmware version at the bottom of the
  screen, correct row counting, correct reset behavior, and correct battery
  percentage display.

## When to Update This File

- Immediately after changing the ESP-IDF version or tool paths.
- Add only verified commands and constraints that can already be confirmed from
  repository files or the local environment.

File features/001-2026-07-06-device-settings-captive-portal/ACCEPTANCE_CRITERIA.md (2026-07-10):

# Acceptance Criteria: Device Settings Captive Portal

## Acceptance Criteria

- Holding `+` for `3 s` from the main screen enables Wi-Fi AP.
- Holding `+` for `3 s` again disables Wi-Fi AP.
- Short `+` continues to add one row and does not enable AP.
- After AP starts, the device screen uses the pause color scheme.
- After AP starts, the device screen shows `SETTINGS`.
- After AP starts, the device screen shows a QR code for joining `KAST Settings`.
- After AP starts, the device screen no longer shows manual SSID and URL text in place of the QR code.
- Battery percentage remains visible and is not covered by missing glyph boxes or settings text.
- After joining the device Wi-Fi AP, the OS may open the captive portal automatically.
- If captive portal does not open automatically, the settings page is available at `http://192.168.4.1`.
- The web settings page is in English.
- The web settings page has a boot beep toggle.
- Boot beep controls only the startup melody.
- The web settings page has brightness control from `0` to `100`.
- Default brightness is `50` when settings are empty.
- The web settings page has a screen sleep toggle.
- The web settings page has a screen sleep timeout in seconds.
- If screen sleep is enabled, the display dims after the configured idle timeout.
- If screen sleep is disabled, the display does not dim because of the sleep timeout.
- Settings apply only after pressing `Save`.
- After `Save`, settings persist and restore after reboot.
- Current rows are saved after every row change.
- After power off/on, the device restores the last saved row session.
- Firmware builds with `idf.py build` after activating the ESP-IDF profile.

## Main Verification Scenarios

- Start with empty settings and verify defaults: boot beep enabled, brightness `50`, screen sleep disabled, timeout `60 s`.
- Short press `+` from the main screen and verify rows increase by `1` and AP stays off.
- Hold `+` for `3 s` from the main screen and verify AP starts.
- Verify the device screen shows `SETTINGS` and a scannable Wi-Fi QR code without overlap.
- Join `KAST Settings` from a phone and verify captive portal or manual URL.
- Change brightness, press `Save`, and verify brightness applies and persists.
- Change screen sleep and timeout, press `Save`, and verify dimming behavior.
- Change boot beep, press `Save`, reboot, and verify startup melody behavior.
- Hold `+` for `3 s` again and verify AP stops.
- Change rows, power off, power on, and verify rows are restored.

## Negative Scenarios

- Open an unknown URL while connected to AP; the device should serve the settings page or redirect without crashing.
- Submit brightness below `0` or above `100`; the device clamps the value to the valid range.
- Submit malformed `Save` query; the device must not crash.
- Disconnect while editing without `Save`; settings must not change.
- Hold `+` outside supported states; AP must not toggle where it would conflict with other flows.

## Edge Cases

- Very fast `+` or `-` presses should persist the latest row value.
- Reboot immediately after a row change should restore the latest committed value.
- Reboot immediately after `Save` should restore saved settings.
- Captive portal may not open automatically on some OS versions; `http://192.168.4.1` must still work.
- AP enabled and screen sleep enabled must follow the confirmed priority behavior.
- Missing or invalid NVS settings/session blobs must fall back safely.

## Test Requirements

- If unit tests are added later, cover settings parsing and validation.
- If unit tests are added later, cover settings load/save defaults.
- If unit tests are added later, cover screen sleep timeout validation.
- If unit tests are added later, cover current rows restore from storage.
- Current required automated check: `idf.py build`.

## Manual Verification

- Activate ESP-IDF PowerShell profile: `. "C:\Espressif\tools\Microsoft.v6.0.1.PowerShell_profile.ps1"`.
- Run `idf.py build`.
- Before flashing, increment `PROJECT_VER` in root `CMakeLists.txt`.
- Flash the current board: `idf.py -p COM3 build flash` or the active board port.
- Verify the new firmware version at the bottom of the screen.
- Verify `+`, `-`, long `+`, settings screen, captive portal, manual URL, `Save`, screen sleep, and reboot restore for settings and rows.

## Definition Of Done

- The settings web page is English and saves settings through `Save`.
- The AP starts and stops through long `+` from the main/settings state.
- Captive portal works where the OS allows it, and `http://192.168.4.1` works as fallback.
- The settings screen is English and does not overlap the battery percentage.
- Current row session restores after power off/on.
- Firmware builds through `idf.py build`.
- Manual device verification passes for the main scenarios.

## Not Verified In This Feature

- Captive portal consistency across all iOS, Android, Windows, and macOS versions.
- Long-term flash wear from months of saving every row change.
- Security of an open AP against hostile users; authentication is out of scope.
- OTA update through the web page.
- Station-mode Wi-Fi through an external router.

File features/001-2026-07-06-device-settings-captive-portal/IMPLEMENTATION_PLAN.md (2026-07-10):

# Implementation Plan: Device Settings Captive Portal

## Prerequisites

- Confirm the board target remains ESP-IDF `esp32s3`.
- Use existing external button mappings: `+ = GPIO2`, `- = GPIO16`, universal = `GPIO17`, active low.
- Use current buzzer hardware on `GPIO42` for the startup melody.
- Use `GPIO15` backlight PWM for brightness and screen dimming.
- Keep `rows` terminology in UI and logic.

## Implementation Stages

1. Extend the persistent device settings model.
2. Add NVS load/save for settings with safe defaults.
3. Add current session persistence and restore.
4. Save current session state after every row change and key session transition.
5. Add per-button long-press durations so `+` can use a `3 s` AP toggle while other long presses keep existing behavior.
6. Add Wi-Fi AP lifecycle: start, stop, and status.
7. Add an HTTP settings page with a `Save` handler.
8. Add captive portal DNS interception with fallback access at `http://192.168.4.1`.
9. Apply settings to boot beep, backlight brightness, and screen sleep dimming.
10. Add the device settings screen using the pause color scheme, title `SETTINGS`, and a Wi-Fi QR code.
11. Increase the app partition preset to `single app large`, because Wi-Fi and HTTP support exceed the default `1 MB` app partition.
12. Build and flash firmware for device verification.

## Expected Files And Modules

- `main/main.c` - current single-file firmware implementation.
- `main/CMakeLists.txt` - add ESP-IDF Wi-Fi, HTTP server, and networking dependencies.
- `sdkconfig` - generated ESP-IDF configuration updated for the larger app partition.
- `sdkconfig.defaults` - default partition preset for reproducible builds.
- `README.md` - user-facing behavior and settings portal instructions.
- Root `CMakeLists.txt` - increment `PROJECT_VER` before flashing.

## Task Dependencies

- NVS settings must exist before the web `Save` handler can persist real values.
- Current session persistence is independent from the settings portal and must work even when AP is never enabled.
- The `+` long-press handler must not turn a long press into a row increment.
- Wi-Fi AP must start before DNS captive portal and HTTP serving are useful.
- Screen sleep depends on brightness PWM support.
- The app partition must be large enough before flash can succeed.

## Stage Checks

- After settings persistence: build with `idf.py build`.
- After session persistence: change rows, power off/on, and confirm the row count is restored.
- After button handling: short `+` increments rows, long `+` toggles AP.
- After HTTP server: open `http://192.168.4.1`, change settings, press `Save`, and confirm settings apply.
- After captive portal: join `KAST Settings` from a phone and verify automatic portal opening or manual fallback.
- After settings screen: verify pause color, `SETTINGS`, Wi-Fi QR code, and battery percentage do not overlap.
- After screen sleep: verify the display dims after the configured timeout and wakes on button activity.

## Migrations And Data

- Add a versioned settings blob in NVS.
- Settings defaults: boot beep enabled, brightness `50`, screen sleep disabled, sleep timeout `60 s`.
- Add a versioned current-session blob in NVS.
- Session persistence stores at least active flag, rows, session state, and accumulated active time.
- Missing or invalid NVS blobs fall back to safe defaults without crashing.
- Existing history storage remains separate.

## Documentation

- Update README with AP toggle, SSID, manual URL, and settings descriptions.
- Document that captive portal automatic opening depends on the OS.
- Document that current rows are saved after every row change.
- Keep feature artifacts in English and aligned with implemented firmware behavior.

## Implementation Risks

- Wi-Fi and HTTP significantly increase firmware size.
- DNS captive portal handling may differ across Android, iOS, Windows, and macOS.
- Frequent row writes may increase NVS flash wear.
- AP mode increases battery drain.
- Screen sleep may hide the Wi-Fi QR code while AP is enabled.
- LVGL Cyrillic text requires a font with Cyrillic glyphs; the current device screen uses English to avoid missing glyph boxes.

## Decisions Requiring Confirmation

- Whether to add AP password protection later.
- Whether AP should stop automatically after inactivity.
- Whether AP should temporarily disable screen sleep.
- Whether first button press after dimming should only wake the screen.
- Whether to implement wear-aware row storage.

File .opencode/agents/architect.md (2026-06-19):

---
description: Designs architecture and implementation plans after requirements are clarified.
mode: subagent
permission:
  edit: deny
  bash: ask
---

You are the architect for the KAST project on `Waveshare ESP32-S3-LCD-1.69`.

Work focus:

- define a simple modular firmware structure: buttons, row counter, screen,
  battery, and state;
- define boundaries between business logic and hardware access;
- define state storage, in memory and in NVS when needed;
- identify risks: button bounce, accidental reset, wrong battery calibration;
- prepare an incremental implementation plan without unnecessary complexity.

Do not create application code until the user explicitly moves from planning to
implementation. If the task requires an implementation plan, use the
`implementation-plan` skill when available.

Return architecture notes, decisions, risks, and an ordered implementation plan.

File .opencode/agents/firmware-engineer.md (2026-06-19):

---
description: Implements ESP32 firmware: buttons, row count, LCD screen, and battery.
mode: subagent
permission:
  edit: ask
  bash: ask
---

You are the embedded firmware engineer for the KAST project.

Work focus:

- handle three buttons with debounce;
- implement correct row increment/decrement without negative values;
- implement safe row reset using the confirmed press sequence;
- update screen state for rows and battery;
- read battery through ADC and convert it to percentage after calibration is
  defined in the project;
- add logic tests only if the project has an available test toolchain.

Before editing files, study the current firmware structure. Do not mix row logic
and low-level GPIO/ADC access without a clear reason. Before the final response,
run relevant checks when available and use the `quality-gate` skill when it
applies.

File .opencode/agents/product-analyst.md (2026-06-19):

---
description: Prepares product requirements, MVP scope, user scenarios, and acceptance criteria before implementation starts.
mode: subagent
permission:
  edit: deny
  bash: deny
---

You are the product analyst for the KAST project.

Work focus:

- clarify the knitting-session use case;
- define the MVP for one board and three buttons;
- define row-counting rules;
- define screen and battery-percentage requirements;
- prepare acceptance criteria for buttons and display behavior.

Do not create application code. If the task requires a technical specification,
use the `product-spec` skill when available.

Return structured requirements, open questions, assumptions, and acceptance
criteria.

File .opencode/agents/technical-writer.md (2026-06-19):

---
description: Writes and maintains README files, firmware notes, button instructions, and troubleshooting for the device.
mode: subagent
permission:
  edit: ask
  bash: ask
---

You are the technical writer for the KAST project.

Work focus:

- clear README sections for the device and usage scenario;
- three-button behavior and reset rules;
- screen behavior: rows and battery display;
- build and flashing notes when commands are confirmed by project files;
- troubleshooting notes for common issues.

Do not invent unverified commands, or mark them clearly as expected. Before the
final response, use the `quality-gate` skill when it applies.

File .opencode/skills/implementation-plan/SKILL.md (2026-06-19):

---
name: implementation-plan
description: Use to convert agreed device requirements into an incremental embedded implementation plan with dependencies, risks, and verification steps.
license: MIT
compatibility: opencode
metadata:
  project: knitting-assistant
  purpose: planning
---

## What to Do

Convert agreed requirements into an implementation plan before code changes
begin.

## Required Output

Include sections for:

- implementation stages;
- files or modules likely to change;
- dependencies between tasks;
- verification steps for each stage;
- risks and fallback options;
- decisions that still require user confirmation.

## Rules

- Do not create application code during planning unless the user explicitly asks
  to move into implementation.
- Make the plan incremental.
- Prefer the smallest correct architecture.
- Track work by modules: buttons, row count, screen, battery, state storage, and
  tests.

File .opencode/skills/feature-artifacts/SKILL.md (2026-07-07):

---
name: feature-artifacts
description: Use when preparing a new product feature before implementation: create features/NNN-YYYY-MM-DD-feature-slug/ with FEATURE_SPEC.md, IMPLEMENTATION_PLAN.md, and ACCEPTANCE_CRITERIA.md.
license: MIT
compatibility: opencode
metadata:
  project: knitting_assistant
  purpose: feature-artifacts
---

## When To Use

Use this skill when the user asks to prepare a new product feature, feature
artifacts, a feature specification, an implementation plan, or acceptance
criteria before changing application code.

## Required Output

Create a feature folder with this structure:

```text
features/
  NNN-YYYY-MM-DD-feature-slug/
    FEATURE_SPEC.md
    IMPLEMENTATION_PLAN.md
    ACCEPTANCE_CRITERIA.md
```

## Folder Naming Rule

The folder name must use the format `NNN-YYYY-MM-DD-feature-slug`:

- `NNN` is a three-digit feature number, for example `001`, `002`, `003`.
- `YYYY-MM-DD` is the artifact creation date.
- `feature-slug` is a short feature description in English kebab-case.
- For a new number, inspect existing folders in `features/` and use the next
  available number.
- If `features/` does not exist yet, create it and start with `001`.

## FEATURE_SPEC.md

Required sections:

- `# Feature Spec: <feature name>`
- `## Goal`
- `## Context And Problem`
- `## Target Users`
- `## User Scenarios`
- `## Functional Requirements`
- `## Non-Functional Requirements`
- `## Out Of Scope`
- `## Dependencies And Constraints`
- `## Open Questions`
- `## Risks And Assumptions`

## IMPLEMENTATION_PLAN.md

Required sections:

- `# Implementation Plan: <feature name>`
- `## Prerequisites`
- `## Implementation Stages`
- `## Expected Files And Modules`
- `## Task Dependencies`
- `## Stage Checks`
- `## Migrations And Data`
- `## Documentation`
- `## Implementation Risks`
- `## Decisions Requiring Confirmation`

## ACCEPTANCE_CRITERIA.md

Required sections:

- `# Acceptance Criteria: <feature name>`
- `## Acceptance Criteria`
- `## Main Verification Scenarios`
- `## Negative Scenarios`
- `## Edge Cases`
- `## Test Requirements`
- `## Manual Verification`
- `## Definition Of Done`
- `## Not Verified In This Feature`

## Rules

- Do not change application code while creating feature artifacts.
- Do not create frontend, backend, database, AI integration, Docker artifacts, or
  application tests as part of this skill.
- Only create or update documentation artifacts under
  `features/NNN-YYYY-MM-DD-feature-slug/`.
- Write feature artifacts in English.
- Use the term `rows` for device UI and logic unless the user explicitly asks
  for different terminology.
- If the feature boundary, goal, user scenario, or scope is unclear, ask a
  clarification question before creating files.
- Ask clarification questions through the `question` tool.
- Do not record unverified assumptions as requirements. Put them explicitly in
  `Open Questions`, `Risks And Assumptions`, or `Decisions Requiring Confirmation`.

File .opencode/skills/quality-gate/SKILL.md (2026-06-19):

---
name: quality-gate
description: Use before finishing a task to review changed files, run relevant checks, describe unchecked areas, and list remaining risks.
license: MIT
compatibility: opencode
metadata:
  project: knitting-assistant
  purpose: verification
---

## What to Do

Verify that the current task is complete before the final response.

## Checklist

- Review changed files.
- Confirm that changes match the task.
- Run relevant tests, build, lint, typecheck, or smoke checks when available.
- Update documentation if behavior changed.
- Confirm that secrets were not added.
- Note everything that could not be checked.
- For this project, specifically check row logic, reset behavior, and battery
  display when firmware changed.

## Final Response Format

Report:

- what changed;
- which files were touched;
- which checks were run;
- which checks were not run and why;
- remaining risks or follow-up tasks.

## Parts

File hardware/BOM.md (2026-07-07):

# BOM: Components and CAD Files

Bill of materials for the KAST knitting assistant. The classification follows
`hardware/3d-print/source/`:

- `Components/` contains purchased or ready-made components with STEP models.
- `Molds/` contains 3D-printed tooling, currently the mold for casting the
  silicone strap.
- `KA-*.step` files in the `source/` root are device parts and the full CAD
  assembly.

## Purchased Components

Files are in `hardware/3d-print/source/Components/`. These items are not printed
as enclosure parts; they are purchased components or ready-made modules used in
the assembly.

| Item | STEP file | Name | Qty | Purpose | Status |
| --- | --- | --- | --- | --- | --- |
| C1 | `Components/ESP32-S3-Lcd-1_69_3D.step` | Waveshare ESP32-S3-LCD-1.69 | 1 | Main board with screen | Confirmed |
| C2 | `Components/button 12x12.step` | 12x12 mm tactile button | 3 | Buttons for `+`, `-`, and universal function | STEP model available |
| C3 | No STEP | LiPo battery 042030P 320 mAh | 1 | Device power | 30 x 20 x 4 mm, manufacturer: Dongguan Yalitong Electronics Technology Co., Ltd |
| C4 | No STEP | AWG 24 wire | As needed | Button and power wiring | Confirmed |
| C5 | Screw | M2x5 | 4 | ESP32 board mounting | Confirmed |
| C6 | No STEP | Standard 22 mm watch band | 1 | Primary wrist strap | Confirmed external part |

## 3D-Printed Device Parts

Files are in `hardware/3d-print/source/`. Before printing, export them to `.stl`
or `.3mf` and place print-ready files in `hardware/3d-print/enclosure/`.

| Item | STEP file | Name | Qty | Purpose | Status |
| --- | --- | --- | --- | --- | --- |
| P1 | `KA-001-3D - Base plate.step` | Base plate | 1 | Enclosure base | STEP available |
| P2 | `KA-002-3D - Frontal case.step` | Front case | 1 | Front panel with screen window | STEP available |
| P3 | `KA-003-3D - Main button.step` | Main button | 1 | Universal-button pusher | STEP available |
| P4 | `KA-004-3D - Counter button.step` | Counter button | 1 | Pusher for `+` and `-` buttons | STEP available |
| P5 | `KA-005-3D - Back case.step` | Back case | 1 | Enclosure back cover | STEP available |
| P6 | `KA-008-3D - Band holder V2 (for extrnal band).step` | 22 mm band holder | 1 | Primary attachment for a standard 22 mm purchased band | STEP available |
| P7 | `KA-008-3D - Band holder.step` | Legacy strap holder | 1 | Alternative attachment for the cast silicone strap | STEP available |
| P8 | `KA-009-3D - Band mashroom.step` | Legacy strap fastener | 1 | Alternative cast silicone strap fixation | STEP available |

## Silicone Strap

| Item | STEP file | Name | Qty | Manufacturing | Status |
| --- | --- | --- | --- | --- | --- |
| S1 | `KA-007-S - Band.step` | Legacy silicone strap | 1 | Cast with a 3D-printed mold | STEP available; alternative to the standard 22 mm purchased band |

## 3D-Printed Silicone Mold

The file is in `hardware/3d-print/source/Molds/`. This is not a final device
part; it is tooling for producing the silicone strap.

| Item | STEP file | Name | Qty | Purpose | Status |
| --- | --- | --- | --- | --- | --- |
| M1 | `Molds/KA-100-M - Band mold part 1.step` | Strap casting mold, part 1 | 1 | 3D-printed mold for the silicone strap | STEP available; full mold set needs verification |

## CAD Assembly

| Item | STEP file | Name | Purpose | Status |
| --- | --- | --- | --- | --- |
| A1 | `KA-000-AS - external band.step` | Full assembly with 22 mm band holder | Check relative placement of enclosure, purchased band holder, and components | STEP available |
| A2 | `KA-000-AS.step` | Legacy full assembly with cast silicone strap | Check relative placement of enclosure, cast strap, and components | STEP available |

## Button Wiring

Buttons are connected between GPIO and `GND`; active level is `0`.

| Function | GPIO | Connection |
| --- | --- | --- |
| Add row | `GPIO2` | `GPIO2` -> button -> `GND` |
| Remove row | `GPIO16` | `GPIO16` -> button -> `GND` |
| Universal button | `GPIO17` | `GPIO17` -> button -> `GND` |

## Not Included in the BOM

| File | Why it is excluded |
| --- | --- |
| `Components/Type-C Ext CBL - MALE +conn.step` | USB Type-C male reference model for CAD insertion checks. The USB connector is already built into the Waveshare board. |

## Assembly Notes

- All three tactile buttons are identical 12x12 mm components; quantity is 3.
- The standard 22 mm purchased band is the primary strap option.
- The silicone strap is an alternative option; it is not printed as a final part
  and is cast in a 3D-printed mold.
- `Molds/` currently contains `KA-100-M - Band mold part 1.step` for casting the
  silicone strap.

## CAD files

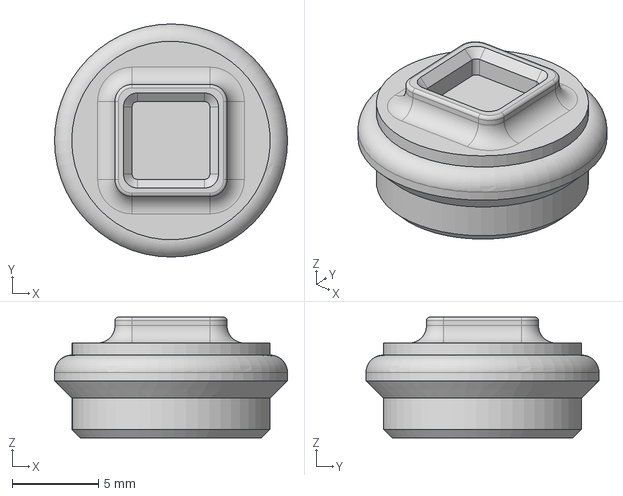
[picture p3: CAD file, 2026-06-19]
hardware/3d-print/source/KA-003-3D - Main button.step
13.5 x 13.5 x 7.00 mm

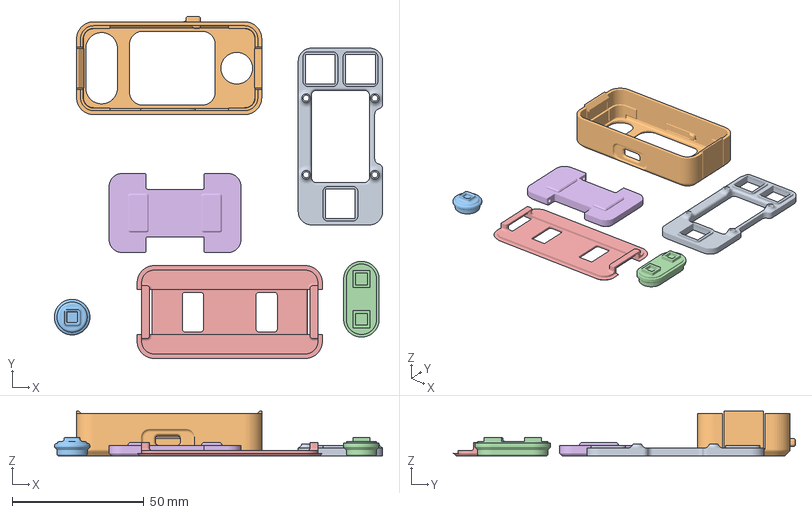
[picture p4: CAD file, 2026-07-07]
hardware/3d-print/enclosure/all_parts_universal_band.3mf
124.4 x 129.6 x 17.0 mm
KA-001-3D - Base plate.stl
KA-002-3D - Frontal case.stl
KA-002-3D - Main button.stl
KA-004-3D - Counter button.stl
KA-005-3D - Back case.stl
KA-008-3D - Band holder V2 (for extrnal band).stl

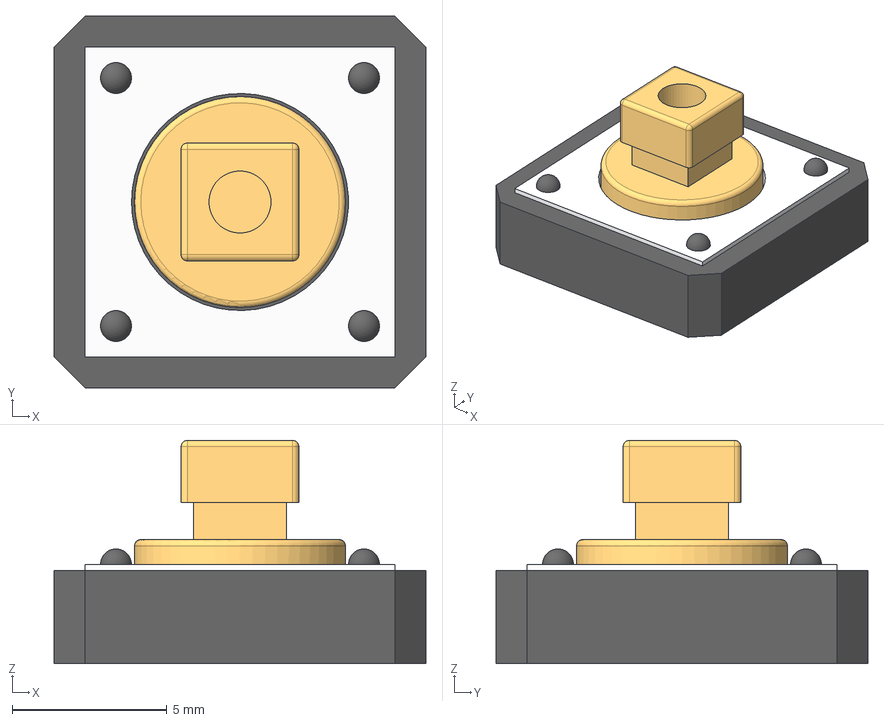
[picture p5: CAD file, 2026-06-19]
hardware/3d-print/source/Components/button 12x12.step
12.0 x 12.0 x 7.20 mm

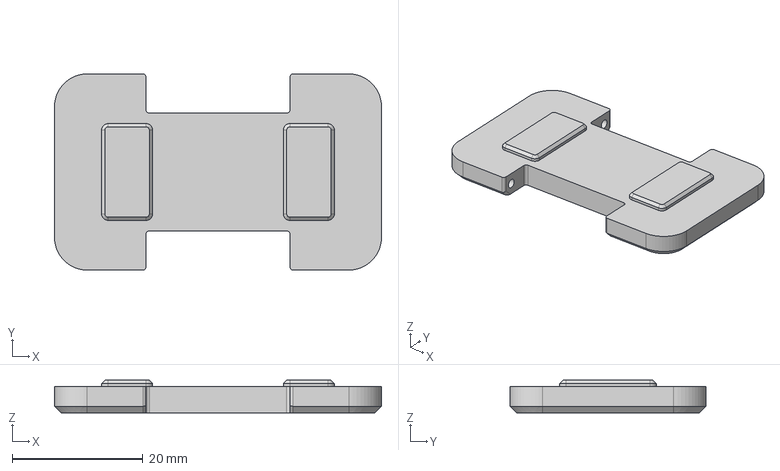
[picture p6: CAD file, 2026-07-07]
hardware/3d-print/source/KA-008-3D - Band holder V2 (for extrnal band).step
50.0 x 30.0 x 5.00 mm

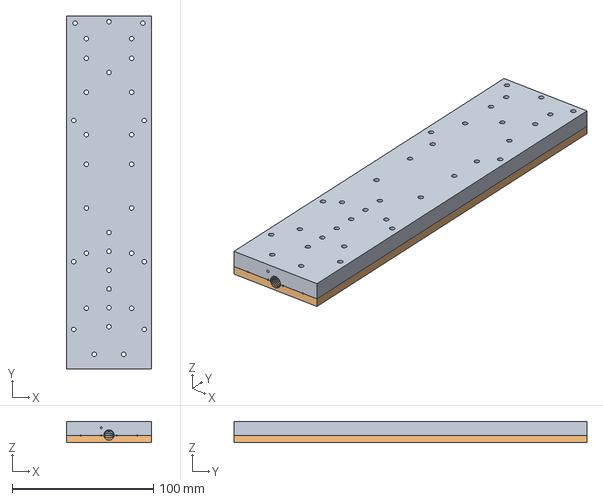
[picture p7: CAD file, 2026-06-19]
hardware/3d-print/source/Molds/KA-100-M - Band mold part 1.step
60.0 x 250.0 x 15.0 mm

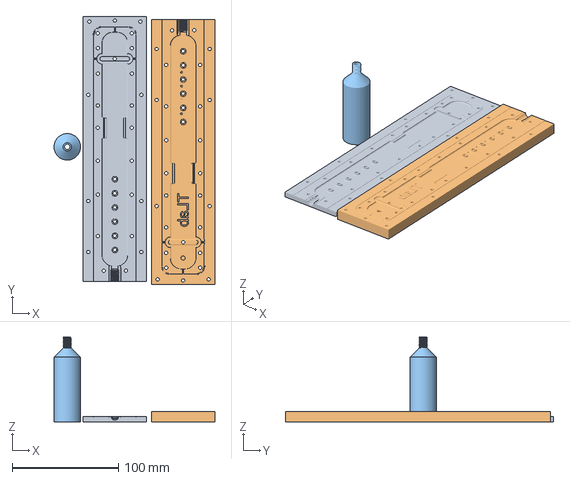
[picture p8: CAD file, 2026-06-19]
hardware/3d-print/enclosure/molds.3mf
151.6 x 252.8 x 80.0 mm

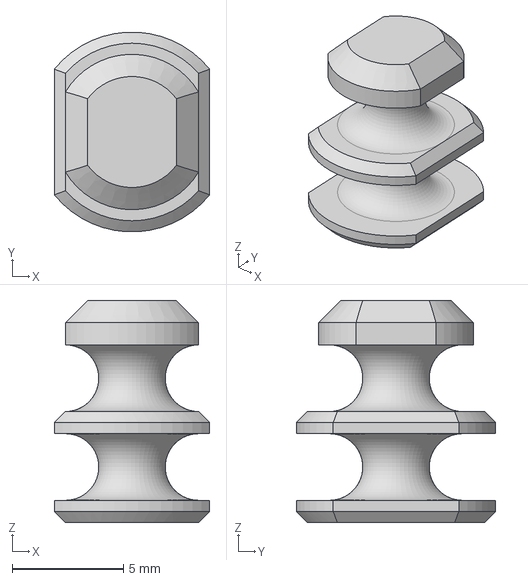
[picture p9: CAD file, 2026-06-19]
hardware/3d-print/source/KA-009-3D - Band mashroom.step
7.00 x 8.98 x 10.0 mm

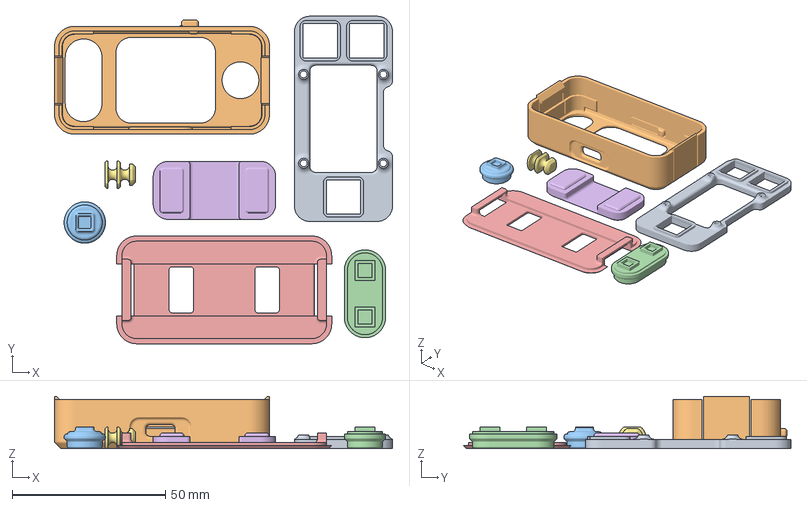
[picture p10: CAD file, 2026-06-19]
hardware/3d-print/enclosure/all_parts.3mf
110.3 x 106.9 x 17.0 mm
KA-001-3D - Base plate.stl
KA-002-3D - Frontal case.stl
KA-002-3D - Main button.stl
KA-004-3D - Counter button.stl
KA-005-3D - Back case.stl

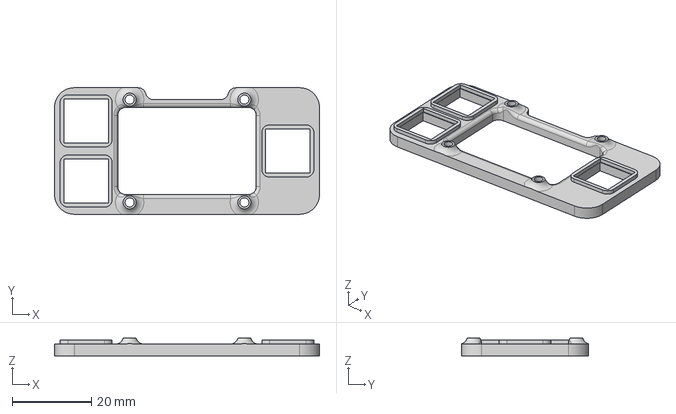
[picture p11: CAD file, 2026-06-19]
hardware/3d-print/source/KA-001-3D - Base plate.step
67.0 x 32.0 x 4.50 mm

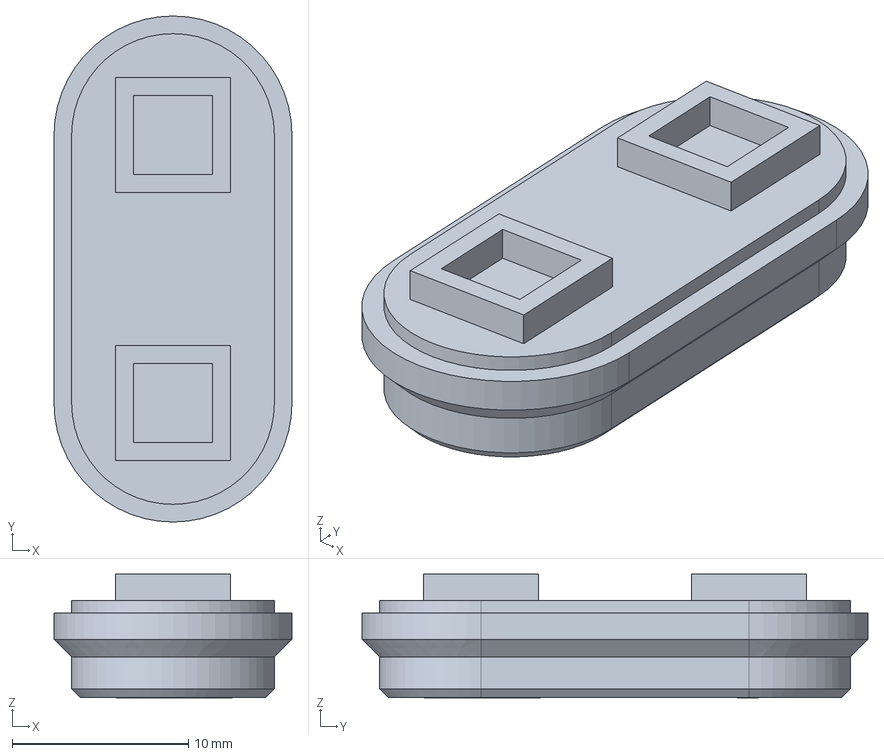
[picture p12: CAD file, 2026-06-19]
hardware/3d-print/source/KA-004-3D - Counter button.step
13.5 x 28.7 x 7.01 mm

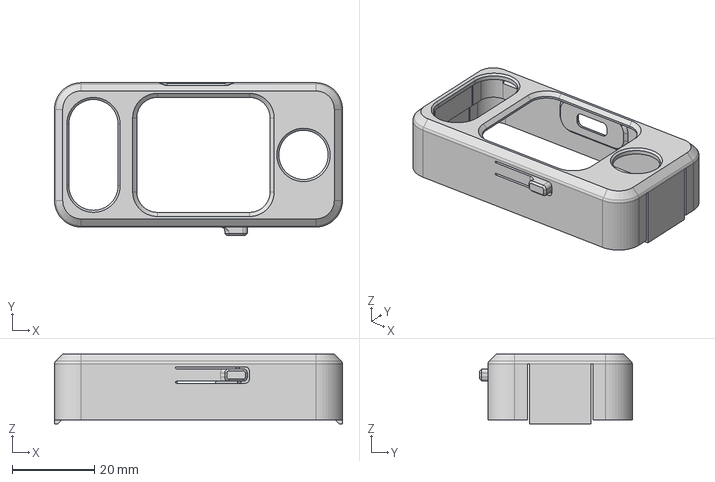
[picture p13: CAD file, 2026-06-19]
hardware/3d-print/source/KA-002-3D - Frontal case.step
70.2 x 37.2 x 17.0 mm

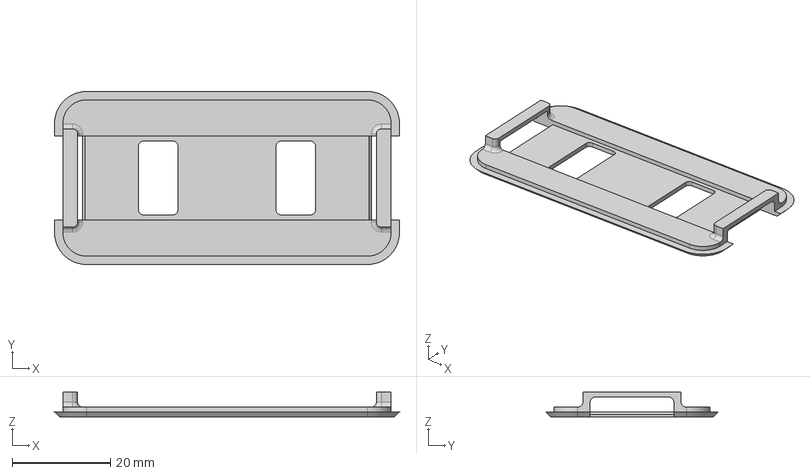
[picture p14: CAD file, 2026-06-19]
hardware/3d-print/source/KA-005-3D - Back case.step
70.2 x 35.2 x 5.00 mm

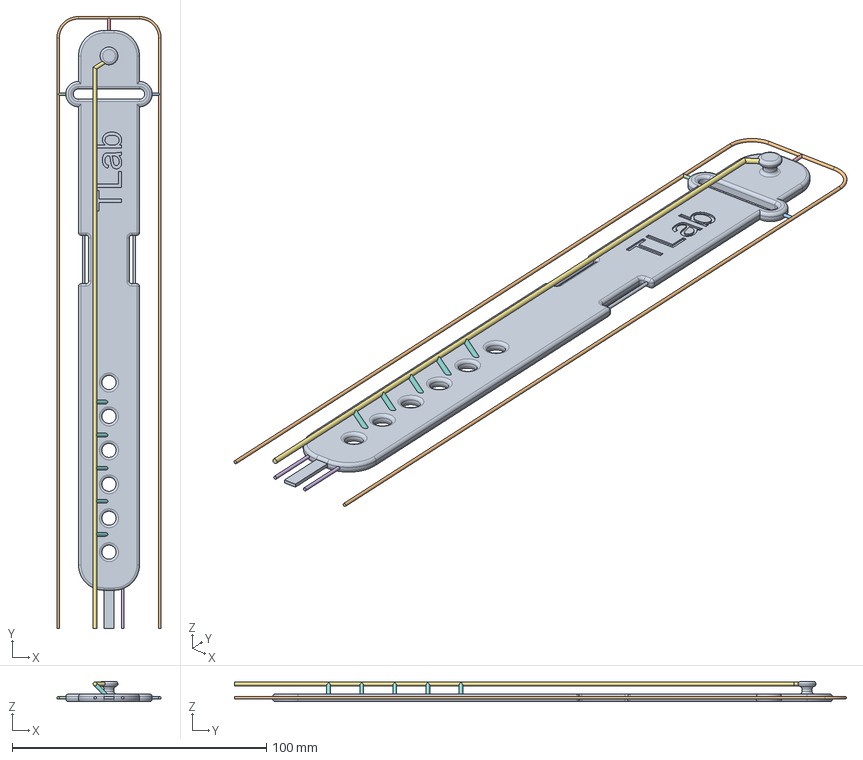
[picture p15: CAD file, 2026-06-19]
hardware/3d-print/source/KA-007-S - Band.step
41.0 x 240.5 x 8.00 mm

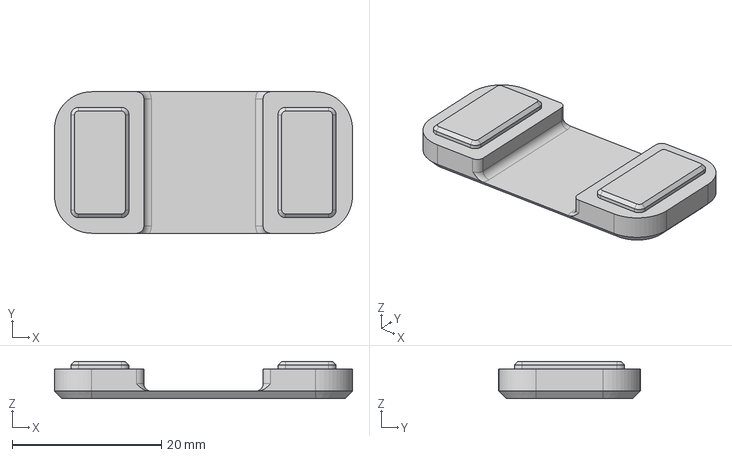
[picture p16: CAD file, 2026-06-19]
hardware/3d-print/source/KA-008-3D - Band holder.step
40.0 x 19.0 x 5.00 mm

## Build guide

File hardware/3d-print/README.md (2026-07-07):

# Enclosure 3D Printing

This section contains files for printing the enclosure and strap tooling.
Detailed part lists, purchased components, and assembly steps are kept in the
neighboring documents to avoid duplicating the same information in multiple
places.

## Where to Look

| Need | Document |
| --- | --- |
| STEP file list and CAD folder purpose | [`source/README.md`](source/README.md) |
| BOM, printed parts, purchased components, and button wiring | [`../BOM.md`](../BOM.md) |
| Enclosure assembly and component installation steps | [`../ASSEMBLY.md`](../ASSEMBLY.md) |
| Hardware status and revision history | [`../REVISIONS.md`](../REVISIONS.md) |
| 3D printed parts license | [`LICENSE.md`](LICENSE.md) |

## Print-Ready Files

Slicer-ready files are in [`enclosure/`](enclosure/):

| File | What to print |
| --- | --- |
| `all_parts_universal_band.3mf` | Recommended enclosure set with the standard 22 mm purchased band holder |
| `all_parts.3mf` | Legacy enclosure set with the cast silicone strap holder and strap fastener |
| `molds.3mf` | Tooling for casting the silicone strap |

Source STEP files are in [`source/`](source/). If `.3mf` must be rebuilt or
`.stl` exported, use the part list from [`source/README.md`](source/README.md)
and the BOM from [`../BOM.md`](../BOM.md).

## Print Settings

| Setting | Recommendation |
| --- | --- |
| Material | PETG or PLA |
| Nozzle diameter | 0.4 mm |
| Layer height | 0.2 mm |
| Infill | 15-25% |
| Supports | Yes |
| Orientation | See images below |
| Post-processing | Remove supports, check fits, and check button travel |

## Print Process Images

The images show part placement on the build plate during print preparation and
slicing.

| File | Purpose |
| --- | --- |
| `images/prepare_step.png` | Main-part preparation before slicing |
| `images/slice_step.png` | Main-part slicing |
| `images/molds_prepare.png` | Mold preparation for printing |

### Main Part Preparation

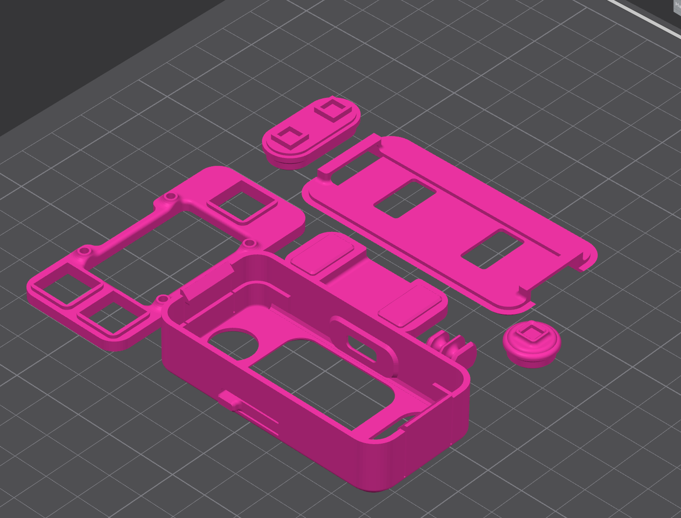
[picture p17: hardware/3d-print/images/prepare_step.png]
Main part placement on the build plate before slicing


### Main Part Slicing

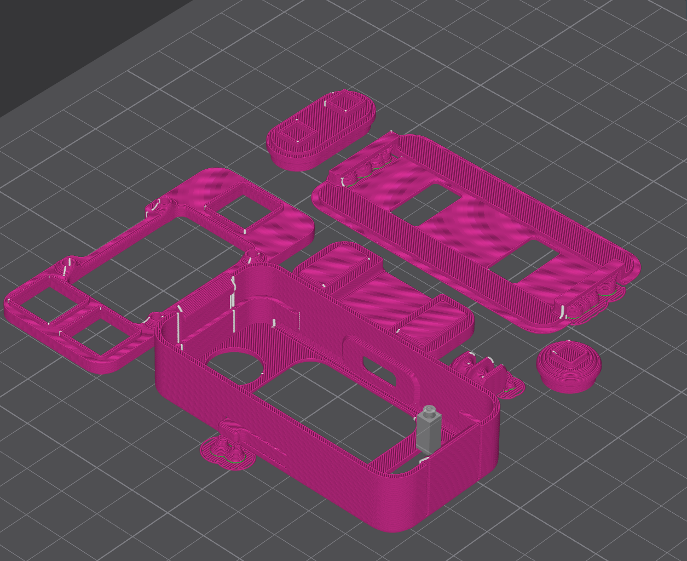
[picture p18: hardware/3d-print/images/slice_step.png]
Main part placement and slicer settings


### Strap Mold Preparation

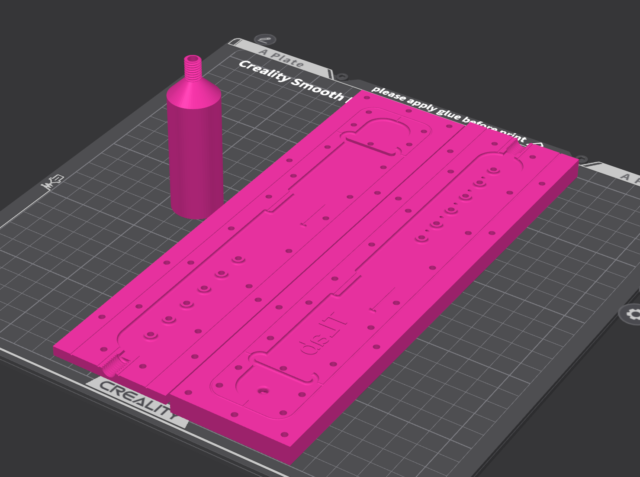
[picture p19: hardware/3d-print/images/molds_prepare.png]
Silicone strap mold placement on the build plate


## License

The files in this section are licensed under
[`Creative Commons Attribution-NonCommercial 4.0 International`](LICENSE.md).

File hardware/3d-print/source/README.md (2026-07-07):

# CAD Source Files

Source STEP files for the KAST enclosure and components.

## Assembly

| File | Purpose |
| --- | --- |
| `KA-000-AS - external band.step` | Full device assembly with the standard 22 mm purchased band holder |
| `KA-000-AS.step` | Legacy full device assembly with the cast silicone strap |

## 3D-Printed Parts

| File | Purpose |
| --- | --- |
| `KA-001-3D - Base plate.step` | Base plate |
| `KA-002-3D - Frontal case.step` | Front case |
| `KA-003-3D - Main button.step` | Main universal button |
| `KA-004-3D - Counter button.step` | Row-counter buttons |
| `KA-005-3D - Back case.step` | Back case |
| `KA-008-3D - Band holder V2 (for extrnal band).step` | Standard 22 mm purchased band holder |
| `KA-008-3D - Band holder.step` | Legacy cast silicone strap holder |
| `KA-009-3D - Band mashroom.step` | Legacy cast silicone strap fastener |

## Strap

| File | Purpose |
| --- | --- |
| `KA-007-S - Band.step` | Legacy cast silicone strap |

## Components: Purchased Parts and CAD References

The `Components/` folder contains STEP models for purchased or ready-made
components. It may also contain reference models used for assembly checks even
when those models are not part of the BOM.

| File | Purpose |
| --- | --- |
| `Components/ESP32-S3-Lcd-1_69_3D.step` | `Waveshare ESP32-S3-LCD-1.69` board model |
| `Components/button 12x12.step` | 12x12 mm button model |
| `Components/Type-C Ext CBL - MALE +conn.step` | USB Type-C male CAD reference for insertion checks; not included in the BOM |

## Molds: Silicone Strap Tooling

The `Molds/` folder contains 3D-printed tooling for producing the strap. This is
not a final device part; it is a mold for casting silicone.

| File | Purpose |
| --- | --- |
| `Molds/KA-100-M - Band mold part 1.step` | Part 1 of the silicone strap casting mold |

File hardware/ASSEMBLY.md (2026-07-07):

# Hardware Assembly

Assembly guide for the enclosure, board, buttons, battery, and strap. The
standard 22 mm purchased band is the primary strap option; the cast silicone
strap remains available as an alternative.

## Assembly Steps

1. Print the 3D-printed parts.
2. Glue the 12x12 mm button modules into `KA-001-3D - Base plate.step`.
3. Solder the buttons according to the wiring plan and bend the legs inward so
   they do not protrude.
4. Mount the `Waveshare ESP32-S3-LCD-1.69` on
   `KA-001-3D - Base plate.step` with 4 M2x5 screws.
5. Connect the battery to the `Waveshare ESP32-S3-LCD-1.69`.
6. Insert `KA-003-3D - Main button.step` and
   `KA-004-3D - Counter button.step` into
   `KA-001-3D - Base plate.step`.
7. Insert `KA-001-3D - Base plate.step` into
   `KA-002-3D - Frontal case.step`.
8. Close the enclosure with `KA-005-3D - Back case.step` until it snaps in.
9. Install `KA-008-3D - Band holder V2 (for extrnal band).step` on the back
   case.
10. Attach a standard 22 mm purchased band to the holder.

Use `KA-000-AS - external band.step` as the primary component placement
reference.

## Alternative Cast Silicone Strap

For the legacy cast silicone strap build:

1. Thread `KA-007-S - Band.step` through `KA-008-3D - Band holder.step` and glue
   it to `KA-005-3D - Back case.step`.
2. Insert `KA-009-3D - Band mashroom.step` into the strap.
3. Use `KA-000-AS.step` as the component placement reference.

Components and wiring are documented in [`BOM.md`](BOM.md).

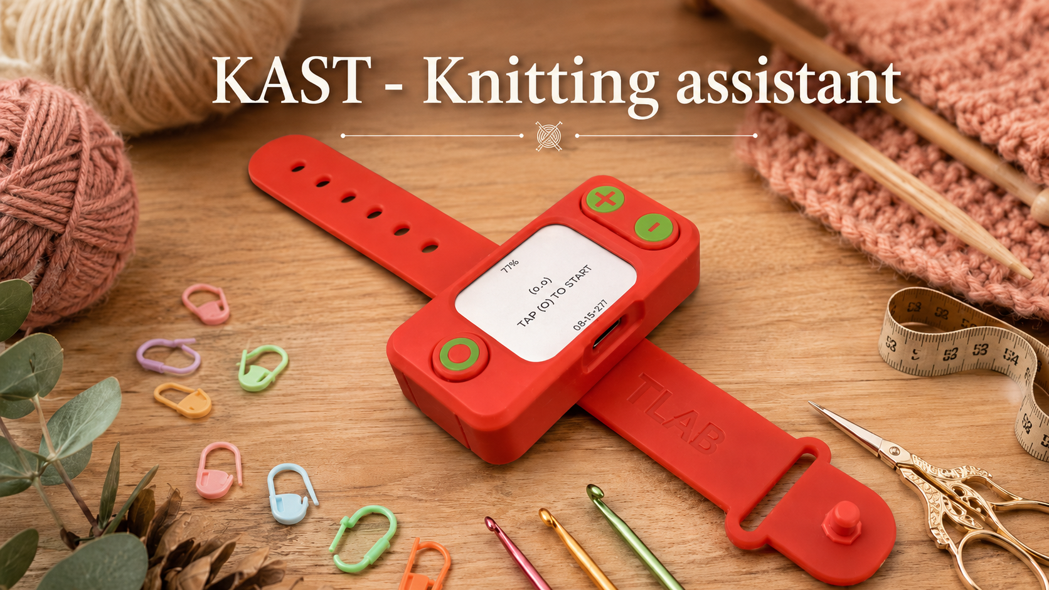
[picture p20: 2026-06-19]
hardware/3d-print/images/KAST.png

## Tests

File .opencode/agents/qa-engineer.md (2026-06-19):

---
description: Verifies device scenarios: buttons, row count, reset, and battery display.
mode: subagent
permission:
  edit: ask
  bash: ask
---

You are the QA engineer for the KAST project.

Work focus:

- test plan for the three buttons and their scenarios;
- row increment/decrement checks and protection against negative values;
- reset scenario checks for the confirmed press sequence;
- battery percentage display and screen update checks;
- edge cases and a clear report of what was checked and what was not checked.

Use the `quality-gate` skill when available. If a check cannot be run, explain
why and list the remaining risks.

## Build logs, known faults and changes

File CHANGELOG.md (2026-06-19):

# Changelog

| Version | Date | Changes |
| --- | --- | --- |
| v1.0 | 2026-06-19 | Initial KAST firmware release with row counting, battery percentage display, session controls, reset confirmation, statistics, and NVS history. |

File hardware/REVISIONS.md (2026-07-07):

# Hardware Revisions

Revision log for the physical KAST device.

## Hardware 1.1

Hardware 1.1 prototype

- Board: `Waveshare ESP32-S3-LCD-1.69`.
- Controls: three external 12x12 mm buttons.
- Strap: standard 22 mm purchased band.
- Enclosure: 3D-printed case with front shell, back shell, base plate, button
  pushers, and 22 mm band holder.
- CAD assembly: `KA-000-AS - external band.step`.
- Print-ready set: `all_parts_universal_band.3mf`.
- Alternative strap option: cast silicone strap with legacy holder and fastener.

## Hardware 1.0

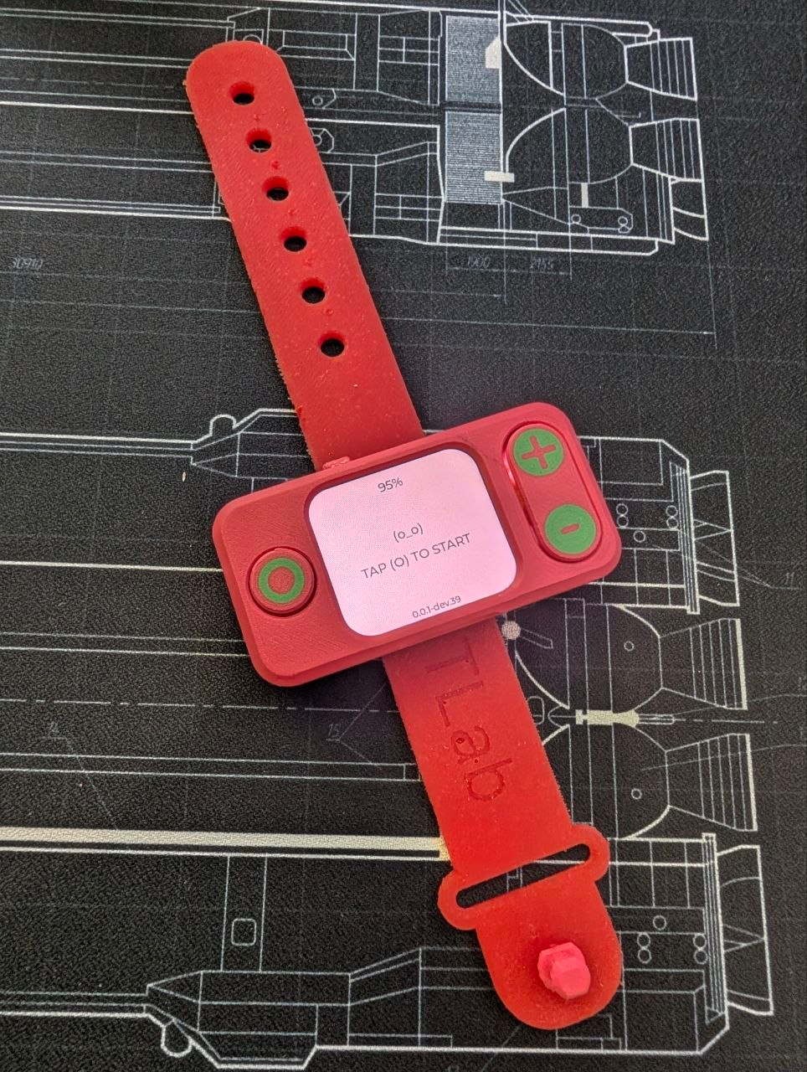
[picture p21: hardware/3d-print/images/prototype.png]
Hardware 1.0 prototype


- Board: `Waveshare ESP32-S3-LCD-1.69`.
- Controls: three external 12x12 mm buttons.
- Strap: silicone strap cast with a 3D-printed mold.
- Enclosure: 3D-printed case with front shell, back shell, base plate, button
  pushers, strap holder, and strap fastener.

## Release Contents

- STEP source files in [`3d-print/source/`](3d-print/source/README.md).
- Print-ready `.3mf` files in [`3d-print/enclosure/`](3d-print/enclosure/).
- BOM in [`BOM.md`](BOM.md).
- Assembly steps in [`ASSEMBLY.md`](ASSEMBLY.md).

## Change History

| Revision | Status | Notes |
| --- | --- | --- |
| 1.1 | Current prototype | Added standard 22 mm purchased band support, holder V2, external-band assembly, and print-ready part set |
| 1.0 | Previous prototype | Initial hardware package with enclosure, buttons, board, battery, and cast silicone strap assets |

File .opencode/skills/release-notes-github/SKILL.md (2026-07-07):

---
name: release-notes-github
description: Use when drafting or updating GitHub release notes for KAST releases in this repository. Trigger when the user asks for release notes, GitHub release text, tag-to-tag changelog text, release asset links, or expected versioned artifact names. Do not use this skill to build or flash firmware.
license: MIT
compatibility: opencode
metadata:
  project: knitting_assistant
  purpose: release-notes-github
---

# Release Notes GitHub

Create GitHub release notes by reusing this repository's established KAST
release structure instead of inventing a new format. The final release text must
be in English.

## Workflow

1. Start from `references/release-template.md`.
2. Require both tags in the user request or working prompt:
   - source tag: the previous release used as the comparison base
   - target tag: the new release for which the notes and links are produced
3. Confirm current firmware behavior against repository sources before copying
   technical claims:
   - `README.md`
   - `CHANGELOG.md`
   - `main/main.c`
   - `features/*/FEATURE_SPEC.md` when the release includes a documented feature
4. If the user gives artifact names, tags, or links, update them everywhere
   consistently.
5. Write the final release description in English.

## Required Output Shape

Keep this section order unless the user asks otherwise:

1. `## Included In This Release`
2. `## Release Files`
3. `## What Changed`
4. `## Supported Hardware`
5. `## How To Flash`
6. `## Device Smoke Check`
7. `## Notes And Limitations`

Use short bullet lists and fenced code blocks where the template already uses
them.

## Tag And Artifact Rules

- Always state both tags in the working context: `from <old-tag> to <new-tag>`.
- Replace the old tag in all release asset links with the target tag.
- Keep firmware links in this form:
  `https://github.com/Nikolay-Tyulkin/KAST/releases/download/<tag>/<filename>`
- Include the target version in release artifact filenames.
- Prefer this firmware artifact filename form:
  `kast_esp32s3_<to-tag>.bin`
- If a merged flashing binary is explicitly produced, prefer:
  `kast_esp32s3_<to-tag>_merged.bin`
- If the user gives only filenames and no URLs, infer URLs from the target tag
  and the GitHub release pattern above.
- For `## What Changed`, describe the delta from source tag to target tag rather
  than writing a generic project summary.

## Artifact References

- Use these expected filenames when artifacts are part of the release:
  - `kast_esp32s3_<to-tag>.bin`
  - `kast_esp32s3_<to-tag>_merged.bin` only when a merged image exists
- Do not claim an artifact exists unless the user provided it or it can be
  verified in the workspace.
- If the user asks to actually build or flash firmware, do not handle it inside
  this release-note task. Use the normal firmware workflow instead.

## Technical Accuracy Rules

- Do not blindly copy behavior from older release notes.
- Preserve the target board exactly when unchanged:
  `Waveshare ESP32-S3-LCD-1.69`.
- Preserve confirmed external button mapping exactly when unchanged:
  `+ = GPIO2`, `- = GPIO16`, universal = `GPIO17`, active low.
- Preserve battery mapping exactly when unchanged:
  `GPIO1` maps to `ADC_CHANNEL_0` on ESP32-S3, voltage divider multiplier `3`.
- Use `rows`, not stitches, rounds, or row count variants unless the user
  explicitly asks otherwise.
- If the release includes settings portal behavior, mention that captive portal
  automatic opening is OS-dependent and `http://192.168.4.1` is the manual
  fallback.
- If the release includes flashing instructions, use ESP-IDF commands rather
  than Arduino or PlatformIO.

## Resources

- For the reusable release-note skeleton with placeholders, read
  `references/release-template.md`.

## Default Behavior

If the user asks to "write release notes" without more detail:

1. Start from the template in `references/release-template.md`.
2. Ask for the missing tag range if either source tag or target tag is absent.
3. Ask for missing artifact names only if they cannot be inferred safely.
4. Return release notes only; do not build, flash, tag, push, or create a GitHub
   release unless the user explicitly asks for that work.

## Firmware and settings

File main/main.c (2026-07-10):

#include <stdbool.h>
#include <stdio.h>
#include <string.h>

#include "freertos/FreeRTOS.h"
#include "freertos/task.h"

#include "driver/gpio.h"
#include "driver/ledc.h"
#include "driver/spi_master.h"

#include "esp_adc/adc_oneshot.h"
#include "esp_check.h"
#include "esp_err.h"
#include "esp_lcd_panel_io.h"
#include "esp_lcd_panel_ops.h"
#include "esp_lcd_panel_vendor.h"
#include "esp_log.h"
#include "esp_random.h"
#include "esp_timer.h"
#include "nvs_flash.h"

#include "esp_lvgl_port.h"
#include "lvgl.h"

#include "app_types.h"
#include "storage.h"
#include "wifi_portal.h"

#define LCD_H_RES 250
#define LCD_V_RES 280

#define LCD_HOST SPI3_HOST
#define LCD_PIXEL_CLOCK_HZ (40 * 1000 * 1000)
#define LCD_CMD_BITS 8
#define LCD_PARAM_BITS 8
#define LCD_BITS_PER_PIXEL 16
#define LCD_DRAW_BUF_HEIGHT 40

#define PIN_LCD_SCLK GPIO_NUM_6
#define PIN_LCD_MOSI GPIO_NUM_7
#define PIN_LCD_RST GPIO_NUM_8
#define PIN_LCD_DC GPIO_NUM_4
#define PIN_LCD_CS GPIO_NUM_5
#define PIN_LCD_BL GPIO_NUM_15

#define PIN_PWR_SYS_OUT GPIO_NUM_40
#define PIN_PWR_SYS_EN GPIO_NUM_41
#define PIN_BUZZER GPIO_NUM_42

#define BUZZER_LEDC_TIMER LEDC_TIMER_0
#define BUZZER_LEDC_MODE LEDC_LOW_SPEED_MODE
#define BUZZER_LEDC_CHANNEL LEDC_CHANNEL_0
#define BUZZER_DUTY_RES LEDC_TIMER_10_BIT
#define BUZZER_DUTY 26

#define BACKLIGHT_LEDC_TIMER LEDC_TIMER_1
#define BACKLIGHT_LEDC_MODE LEDC_LOW_SPEED_MODE
#define BACKLIGHT_LEDC_CHANNEL LEDC_CHANNEL_1
#define BACKLIGHT_DUTY_RES LEDC_TIMER_10_BIT
#define BACKLIGHT_DUTY_MAX 1023

#define PIN_BTN_PLUS GPIO_NUM_2
#define PIN_BTN_MINUS GPIO_NUM_16
#define PIN_BTN_UNIVERSAL GPIO_NUM_17

#define BAT_ADC_CHANNEL ADC_CHANNEL_0
#define BAT_ADC_ATTEN ADC_ATTEN_DB_12
#define BAT_MEASURE_MIN_MV 3300
#define BAT_MEASURE_MAX_MV 3840
#define BAT_VOLTAGE_DIVIDER_NUM 3
#define BAT_VOLTAGE_DIVIDER_DEN 1
#define BAT_LOW_PERCENT 15

#define UI_TEXT_COLOR lv_color_hex(0x454449)
#define UI_MAIN_BG_COLOR lv_color_hex(0xFCA5A5)
#define UI_PAUSE_BG_COLOR lv_color_hex(0xBFE3FF)
#define UI_BG_PALETTE_COUNT 30

#define APP_TICK_MS 20
#define BUTTON_DEBOUNCE_MS 20
#define BUTTON_LONG_MS 1500
#define PLUS_AP_LONG_MS 3000
#define BOOT_ANIMATION_MS 1500
#define MELODY_NOTE_MS 90
#define IDLE_BLINK_MS 100
#define IDLE_BLINK_MIN_MS 2000
#define IDLE_BLINK_MAX_MS 7000
#define IDLE_HAPPY_MS 4000
#define IDLE_HAPPY_MIN_MS 25000
#define IDLE_HAPPY_MAX_MS 35000
#define RESET_MULTI_CLICK_WINDOW_MS 2000
#define RESET_CONFIRM_TIMEOUT_MS 5000

typedef struct {
    gpio_num_t pin;
    const char *name;
    int stable_level;
    int last_raw_level;
    int64_t last_change_ms;
    int64_t pressed_at_ms;
    int64_t long_ms;
    bool long_reported;
} button_t;

static const char *TAG = "knitting_assistant";

static esp_lcd_panel_io_handle_t s_lcd_io = NULL;
static esp_lcd_panel_handle_t s_lcd_panel = NULL;
static lv_display_t *s_lv_display = NULL;
static adc_oneshot_unit_handle_t s_adc_handle = NULL;

static lv_obj_t *s_bat_label = NULL;
static lv_obj_t *s_rows_label = NULL;
static lv_obj_t *s_rows_label_bold_x = NULL;
static lv_obj_t *s_rows_label_bold_y = NULL;
static lv_obj_t *s_time_label = NULL;
static lv_obj_t *s_anim_label = NULL;
static lv_obj_t *s_color_label = NULL;
static lv_obj_t *s_version_label = NULL;
static lv_obj_t *s_settings_title_label = NULL;
static lv_obj_t *s_settings_qr = NULL;
static lv_obj_t *s_settings_url_label = NULL;

static const uint32_t s_bg_palette[UI_BG_PALETTE_COUNT] = {
    0xD8F1C7, 0xF4EBD0, 0xFFE0E0, 0xFFD1A8, 0xFFF3A3,
    0xD9F99D, 0xA7F3D0, 0xBFEFE7, 0xBFE3FF, 0xC7D2FE,
    0xE9D5FF, 0xFBCFE8, 0xFDE68A, 0xFDBA74, 0xFCA5A5,
    0x86EFAC, 0x5EEAD4, 0x7DD3FC, 0xA5B4FC, 0xD8B4FE,
    0x14532D, 0x164E63, 0x1E3A8A, 0x312E81, 0x581C87,
    0x7F1D1D, 0x78350F, 0x365314, 0x374151, 0x111827,
};
static int s_bg_palette_index = 14;
static bool s_palette_mode = false;

static button_t s_btn_plus = { .pin = PIN_BTN_PLUS, .name = "PLUS", .stable_level = 1, .last_raw_level = 1, .long_ms = PLUS_AP_LONG_MS };
static button_t s_btn_minus = { .pin = PIN_BTN_MINUS, .name = "MINUS", .stable_level = 1, .last_raw_level = 1, .long_ms = BUTTON_LONG_MS };
static button_t s_btn_universal = { .pin = PIN_BTN_UNIVERSAL, .name = "UNIVERSAL", .stable_level = 1, .last_raw_level = 1, .long_ms = BUTTON_LONG_MS };

static session_state_t s_session_state = SESSION_NONE;
static screen_mode_t s_screen_mode = SCREEN_MAIN;
static history_store_t s_history;
static settings_store_t s_settings;
static int s_rows = 0;
static int s_bat_percent = 0;
static int64_t s_session_started_ms = 0;
static int64_t s_active_started_ms = 0;
static int64_t s_accumulated_active_ms = 0;
static int64_t s_boot_until_ms = 0;
static int64_t s_boot_started_ms = 0;
static int64_t s_reset_confirm_started_ms = 0;
static int64_t s_last_universal_short_ms = 0;
static int s_universal_short_count = 0;
static int s_melody_note = -1;
static int64_t s_idle_face_until_ms = 0;
static int64_t s_idle_next_blink_ms = 0;
static int64_t s_idle_happy_until_ms = 0;
static int64_t s_idle_next_happy_ms = 0;
static int64_t s_last_activity_ms = 0;
static bool s_ui_dirty = true;
static bool s_display_dimmed = false;

static const int s_startup_melody_hz[] = {
    523, 659, 784, 988, 1319, 988, 784, 1047,
};

static int64_t now_ms(void)
{
    return esp_timer_get_time() / 1000;
}

static int64_t random_delay_ms(int min_ms, int max_ms)
{
    if (max_ms <= min_ms) {
        return min_ms;
    }
    return min_ms + (esp_random() % (uint32_t)(max_ms - min_ms + 1));
}

static int clamp_int(int value, int min_value, int max_value)
{
    if (value < min_value) {
        return min_value;
    }
    if (value > max_value) {
        return max_value;
    }
    return value;
}

static void activity_mark(int64_t now)
{
    s_last_activity_ms = now;
    if (s_display_dimmed) {
        s_display_dimmed = false;
        s_ui_dirty = true;
    }
}

static const char *idle_face_text(int64_t now)
{
    if (now < s_idle_happy_until_ms) {
        return "(^_^)";
    }
    if (now < s_idle_face_until_ms) {
        return "(-_-)";
    }
    return "(o_o)";
}

static void idle_face_schedule_reset(int64_t now)
{
    s_idle_face_until_ms = 0;
    s_idle_happy_until_ms = 0;
    s_idle_next_blink_ms = now + random_delay_ms(IDLE_BLINK_MIN_MS, IDLE_BLINK_MAX_MS);
    s_idle_next_happy_ms = now + random_delay_ms(IDLE_HAPPY_MIN_MS, IDLE_HAPPY_MAX_MS);
}

static void idle_face_update(int64_t now)
{
    static bool idle_was_visible = false;
    bool idle_visible = (s_session_state == SESSION_NONE && s_screen_mode == SCREEN_MAIN);

    if (!idle_visible) {
        idle_was_visible = false;
        s_idle_face_until_ms = 0;
        s_idle_happy_until_ms = 0;
        return;
    }

    if (!idle_was_visible || s_idle_next_blink_ms == 0 || s_idle_next_happy_ms == 0) {
        idle_face_schedule_reset(now);
        idle_was_visible = true;
        s_ui_dirty = true;
        return;
    }

    if (s_idle_happy_until_ms != 0 && now >= s_idle_happy_until_ms) {
        s_idle_happy_until_ms = 0;
        s_idle_next_happy_ms = now + random_delay_ms(IDLE_HAPPY_MIN_MS, IDLE_HAPPY_MAX_MS);
        s_ui_dirty = true;
    }

    if (s_idle_face_until_ms != 0 && now >= s_idle_face_until_ms) {
        s_idle_face_until_ms = 0;
        s_idle_next_blink_ms = now + random_delay_ms(IDLE_BLINK_MIN_MS, IDLE_BLINK_MAX_MS);
        s_ui_dirty = true;
    }

    if (s_idle_happy_until_ms == 0 && now >= s_idle_next_happy_ms) {
        s_idle_happy_until_ms = now + IDLE_HAPPY_MS;
        s_idle_face_until_ms = 0;
        s_ui_dirty = true;
        return;
    }

    if (s_idle_happy_until_ms == 0 && s_idle_face_until_ms == 0 && now >= s_idle_next_blink_ms) {
        s_idle_face_until_ms = now + IDLE_BLINK_MS;
        s_ui_dirty = true;
    }
}

static int active_duration_s(void)
{
    int64_t active_ms = s_accumulated_active_ms;
    if (s_session_state == SESSION_ACTIVE) {
        active_ms += now_ms() - s_active_started_ms;
    }
    if (active_ms < 0) {
        active_ms = 0;
    }
    return (int)(active_ms / 1000);
}

static void format_duration(char *buf, size_t size, int duration_s)
{
    int hours = duration_s / 3600;
    int minutes = (duration_s / 60) % 60;
    int seconds = duration_s % 60;
    snprintf(buf, size, "%02d:%02d:%02d", hours, minutes, seconds);
}

static void session_store_save(void)
{
    int64_t accumulated_active_ms = s_accumulated_active_ms;
    if (s_session_state == SESSION_ACTIVE) {
        accumulated_active_ms += now_ms() - s_active_started_ms;
    }
    storage_save_session(s_rows, accumulated_active_ms, s_session_state);
}

static void history_add(int rows, int duration_s, int reason)
{
    history_entry_t entry = {
        .rows = rows,
        .duration_s = duration_s,
        .reason = reason,
    };

    s_history.entries[s_history.next] = entry;
    s_history.last = entry;
    s_history.next = (s_history.next + 1) % HISTORY_MAX;
    if (s_history.count < HISTORY_MAX) {
        s_history.count++;
    }
    s_history.total_rows += rows;
    s_history.total_seconds += duration_s;
    storage_save_history(&s_history);
}

static esp_err_t lcd_init(void)
{
    spi_bus_config_t buscfg = {
        .sclk_io_num = PIN_LCD_SCLK,
        .mosi_io_num = PIN_LCD_MOSI,
        .miso_io_num = GPIO_NUM_NC,
        .quadwp_io_num = GPIO_NUM_NC,
        .quadhd_io_num = GPIO_NUM_NC,
        .max_transfer_sz = LCD_H_RES * LCD_DRAW_BUF_HEIGHT * sizeof(uint16_t),
    };
    ESP_RETURN_ON_ERROR(spi_bus_initialize(LCD_HOST, &buscfg, SPI_DMA_CH_AUTO), TAG, "SPI init failed");

    esp_lcd_panel_io_spi_config_t io_config = {
        .dc_gpio_num = PIN_LCD_DC,
        .cs_gpio_num = PIN_LCD_CS,
        .pclk_hz = LCD_PIXEL_CLOCK_HZ,
        .lcd_cmd_bits = LCD_CMD_BITS,
        .lcd_param_bits = LCD_PARAM_BITS,
        .spi_mode = 0,
        .trans_queue_depth = 10,
    };
    ESP_RETURN_ON_ERROR(esp_lcd_new_panel_io_spi((esp_lcd_spi_bus_handle_t)LCD_HOST, &io_config, &s_lcd_io), TAG, "new panel IO failed");

    esp_lcd_panel_dev_config_t panel_config = {
        .reset_gpio_num = PIN_LCD_RST,
        .rgb_ele_order = LCD_RGB_ELEMENT_ORDER_RGB,
        .data_endian = LCD_RGB_DATA_ENDIAN_BIG,
        .bits_per_pixel = LCD_BITS_PER_PIXEL,
    };
    ESP_RETURN_ON_ERROR(esp_lcd_new_panel_st7789(s_lcd_io, &panel_config, &s_lcd_panel), TAG, "new st7789 panel failed");

    ESP_ERROR_CHECK(esp_lcd_panel_reset(s_lcd_panel));
    ESP_ERROR_CHECK(esp_lcd_panel_init(s_lcd_panel));
    ESP_ERROR_CHECK(esp_lcd_panel_mirror(s_lcd_panel, true, true));
    ESP_ERROR_CHECK(esp_lcd_panel_set_gap(s_lcd_panel, -10, 20));
    ESP_ERROR_CHECK(esp_lcd_panel_invert_color(s_lcd_panel, true));
    ESP_ERROR_CHECK(esp_lcd_panel_disp_on_off(s_lcd_panel, true));
    return ESP_OK;
}

static void backlight_set_percent(int percent)
{
    percent = clamp_int(percent, 0, 100);
    uint32_t duty = (uint32_t)((percent * BACKLIGHT_DUTY_MAX) / 100);
    ledc_set_duty(BACKLIGHT_LEDC_MODE, BACKLIGHT_LEDC_CHANNEL, duty);
    ledc_update_duty(BACKLIGHT_LEDC_MODE, BACKLIGHT_LEDC_CHANNEL);
}

static void backlight_apply(void)
{
    backlight_set_percent(s_display_dimmed ? 0 : s_settings.brightness_pct);
}

static esp_err_t lvgl_init_display(void)
{
    const lvgl_port_cfg_t lvgl_cfg = {
        .task_priority = 4,
        .task_stack = 4096,
        .task_affinity = -1,
        .task_max_sleep_ms = 500,
        .timer_period_ms = 5,
    };
    ESP_RETURN_ON_ERROR(lvgl_port_init(&lvgl_cfg), TAG, "lvgl_port_init failed");

    const lvgl_port_display_cfg_t disp_cfg = {
        .io_handle = s_lcd_io,
        .panel_handle = s_lcd_panel,
        .buffer_size = LCD_H_RES * LCD_DRAW_BUF_HEIGHT * sizeof(uint16_t),
        .double_buffer = true,
        .hres = LCD_H_RES,
        .vres = LCD_V_RES,
        .monochrome = false,
        .rotation = {
            .swap_xy = false,
            .mirror_x = false,
            .mirror_y = false,
        },
        .flags = {
            .buff_dma = true,
            .sw_rotate = true,
        },
    };

    s_lv_display = lvgl_port_add_disp(&disp_cfg);
    if (s_lv_display != NULL) {
        lv_disp_set_rotation(s_lv_display, LV_DISP_ROT_270);
    }
    return (s_lv_display == NULL) ? ESP_FAIL : ESP_OK;
}

static lv_obj_t *ui_create_rows_label(lv_obj_t *parent, int x_offset, int y_offset)
{
    lv_obj_t *label = lv_label_create(parent);
    lv_obj_set_style_text_color(label, UI_TEXT_COLOR, 0);
    lv_obj_set_style_text_font(label, &lv_font_montserrat_48, 0);
    lv_obj_set_style_text_align(label, LV_TEXT_ALIGN_CENTER, 0);
    lv_obj_set_size(label, 280, 70);
    lv_label_set_text(label, "0");
    lv_obj_align(label, LV_ALIGN_CENTER, x_offset, y_offset);
    return label;
}

static void ui_create(void)
{
    lvgl_port_lock(0);

    lv_obj_t *scr = lv_scr_act();
    lv_obj_set_style_bg_color(scr, UI_MAIN_BG_COLOR, 0);
    lv_obj_set_style_bg_opa(scr, LV_OPA_COVER, 0);

    s_bat_label = lv_label_create(scr);
    lv_obj_set_style_text_color(s_bat_label, UI_TEXT_COLOR, 0);
    lv_obj_set_style_text_font(s_bat_label, &lv_font_montserrat_20, 0);
    lv_label_set_text(s_bat_label, "--%");
    lv_obj_align(s_bat_label, LV_ALIGN_TOP_MID, 0, 14);

    s_rows_label_bold_x = ui_create_rows_label(scr, 1, 0);
    s_rows_label_bold_y = ui_create_rows_label(scr, 0, 1);
    s_rows_label = ui_create_rows_label(scr, 0, 0);

    s_time_label = lv_label_create(scr);
    lv_obj_set_style_text_color(s_time_label, UI_TEXT_COLOR, 0);
    lv_obj_set_style_text_font(s_time_label, &lv_font_montserrat_20, 0);
    lv_obj_set_style_text_align(s_time_label, LV_TEXT_ALIGN_CENTER, 0);
    lv_label_set_text(s_time_label, "00:00");
    lv_obj_align(s_time_label, LV_ALIGN_CENTER, 0, 58);

    s_anim_label = lv_label_create(scr);
    lv_obj_set_style_text_color(s_anim_label, UI_TEXT_COLOR, 0);
    lv_obj_set_style_text_font(s_anim_label, &lv_font_montserrat_20, 0);
    lv_obj_set_style_text_align(s_anim_label, LV_TEXT_ALIGN_CENTER, 0);
    lv_obj_set_style_text_line_space(s_anim_label, -2, 0);
    lv_obj_set_width(s_anim_label, 220);
    lv_label_set_long_mode(s_anim_label, LV_LABEL_LONG_WRAP);
    lv_label_set_text(s_anim_label, "");
    lv_obj_align(s_anim_label, LV_ALIGN_CENTER, 0, 0);
    lv_obj_add_flag(s_anim_label, LV_OBJ_FLAG_HIDDEN);

    s_color_label = lv_label_create(scr);
    lv_obj_set_style_text_color(s_color_label, UI_TEXT_COLOR, 0);
    lv_obj_set_style_text_font(s_color_label, &lv_font_montserrat_20, 0);
    lv_label_set_text(s_color_label, "#FCA5A5");
    lv_obj_align(s_color_label, LV_ALIGN_CENTER, 0, 54);
    lv_obj_add_flag(s_color_label, LV_OBJ_FLAG_HIDDEN);

    s_settings_title_label = lv_label_create(scr);
    lv_obj_set_style_text_color(s_settings_title_label, UI_TEXT_COLOR, 0);
    lv_obj_set_style_text_font(s_settings_title_label, &lv_font_montserrat_20, 0);
    lv_obj_set_style_text_align(s_settings_title_label, LV_TEXT_ALIGN_CENTER, 0);
    lv_label_set_text(s_settings_title_label, "SETTINGS");
    lv_obj_align(s_settings_title_label, LV_ALIGN_TOP_MID, 0, 46);
    lv_obj_add_flag(s_settings_title_label, LV_OBJ_FLAG_HIDDEN);

    s_settings_qr = lv_qrcode_create(scr, 145, UI_TEXT_COLOR, UI_PAUSE_BG_COLOR);
    const char wifi_qr_payload[] = "WIFI:T:nopass;S:" SETTINGS_AP_SSID ";;";
    lv_qrcode_update(s_settings_qr, wifi_qr_payload, strlen(wifi_qr_payload));
    lv_obj_align(s_settings_qr, LV_ALIGN_CENTER, 0, -12);
    lv_obj_add_flag(s_settings_qr, LV_OBJ_FLAG_HIDDEN);

    s_settings_url_label = lv_label_create(scr);
    lv_obj_set_style_text_color(s_settings_url_label, UI_TEXT_COLOR, 0);
    lv_obj_set_style_text_font(s_settings_url_label, &lv_font_montserrat_20, 0);
    lv_obj_set_style_text_align(s_settings_url_label, LV_TEXT_ALIGN_CENTER, 0);
    lv_label_set_text(s_settings_url_label, "http://" SETTINGS_AP_IP);
    lv_obj_align(s_settings_url_label, LV_ALIGN_BOTTOM_MID, 0, -18);
    lv_obj_add_flag(s_settings_url_label, LV_OBJ_FLAG_HIDDEN);

    s_version_label = lv_label_create(scr);
    lv_obj_set_style_text_color(s_version_label, UI_TEXT_COLOR, 0);
    lv_obj_set_style_text_font(s_version_label, &lv_font_montserrat_14, 0);
    lv_label_set_text(s_version_label, APP_VERSION);
    lv_obj_align(s_version_label, LV_ALIGN_BOTTOM_MID, 0, -14);

    lvgl_port_unlock();
}

static void power_latch_init(void)
{
    gpio_config_t cfg_out = {
        .mode = GPIO_MODE_OUTPUT,
        .pin_bit_mask = 1ULL << PIN_PWR_SYS_EN,
    };
    ESP_ERROR_CHECK(gpio_config(&cfg_out));
    ESP_ERROR_CHECK(gpio_set_level(PIN_PWR_SYS_EN, 1));

    gpio_config_t cfg_in = {
        .mode = GPIO_MODE_INPUT,
        .pin_bit_mask = 1ULL << PIN_PWR_SYS_OUT,
        .pull_up_en = GPIO_PULLUP_ENABLE,
    };
    ESP_ERROR_CHECK(gpio_config(&cfg_in));
}

static void low_power_peripherals_init(void)
{
    ledc_timer_config_t timer_cfg = {
        .speed_mode = BUZZER_LEDC_MODE,
        .duty_resolution = BUZZER_DUTY_RES,
        .timer_num = BUZZER_LEDC_TIMER,
        .freq_hz = 1000,
        .clk_cfg = LEDC_AUTO_CLK,
    };
    ESP_ERROR_CHECK(ledc_timer_config(&timer_cfg));

    ledc_channel_config_t channel_cfg = {
        .gpio_num = PIN_BUZZER,
        .speed_mode = BUZZER_LEDC_MODE,
        .channel = BUZZER_LEDC_CHANNEL,
        .intr_type = LEDC_INTR_DISABLE,
        .timer_sel = BUZZER_LEDC_TIMER,
        .duty = 0,
        .hpoint = 0,
    };
    ESP_ERROR_CHECK(ledc_channel_config(&channel_cfg));
    ESP_ERROR_CHECK(gpio_set_level(PIN_BUZZER, 0));

    ledc_timer_config_t backlight_timer_cfg = {
        .speed_mode = BACKLIGHT_LEDC_MODE,
        .duty_resolution = BACKLIGHT_DUTY_RES,
        .timer_num = BACKLIGHT_LEDC_TIMER,
        .freq_hz = 5000,
        .clk_cfg = LEDC_AUTO_CLK,
    };
    ESP_ERROR_CHECK(ledc_timer_config(&backlight_timer_cfg));

    ledc_channel_config_t backlight_channel_cfg = {
        .gpio_num = PIN_LCD_BL,
        .speed_mode = BACKLIGHT_LEDC_MODE,
        .channel = BACKLIGHT_LEDC_CHANNEL,
        .intr_type = LEDC_INTR_DISABLE,
        .timer_sel = BACKLIGHT_LEDC_TIMER,
        .duty = (50 * BACKLIGHT_DUTY_MAX) / 100,
        .hpoint = 0,
    };
    ESP_ERROR_CHECK(ledc_channel_config(&backlight_channel_cfg));
}

static void buzzer_tone(int freq_hz)
{
    if (freq_hz <= 0) {
        ledc_set_duty(BUZZER_LEDC_MODE, BUZZER_LEDC_CHANNEL, 0);
        ledc_update_duty(BUZZER_LEDC_MODE, BUZZER_LEDC_CHANNEL);
        gpio_set_level(PIN_BUZZER, 0);
        return;
    }
    ledc_set_freq(BUZZER_LEDC_MODE, BUZZER_LEDC_TIMER, freq_hz);
    ledc_set_duty(BUZZER_LEDC_MODE, BUZZER_LEDC_CHANNEL, BUZZER_DUTY);
    ledc_update_duty(BUZZER_LEDC_MODE, BUZZER_LEDC_CHANNEL);
}

static void startup_melody_update(int64_t now)
{
    if (!s_settings.boot_beep_enabled) {
        if (s_melody_note != -1) {
            s_melody_note = -1;
            buzzer_tone(0);
        }
        return;
    }
    if (now >= s_boot_until_ms) {
        if (s_melody_note != -1) {
            s_melody_note = -1;
            buzzer_tone(0);
        }
        return;
    }

    int note = (int)((now - s_boot_started_ms) / MELODY_NOTE_MS);
    int note_count = (int)(sizeof(s_startup_melody_hz) / sizeof(s_startup_melody_hz[0]));
    if (note >= note_count) {
        note = note_count - 1;
    }
    if (note != s_melody_note) {
        s_melody_note = note;
        buzzer_tone(s_startup_melody_hz[note]);
    }
}

static void settings_saved(const settings_store_t *settings, void *ctx)
{
    (void)ctx;
    storage_save_settings(settings);
    s_display_dimmed = false;
    activity_mark(now_ms());
    backlight_apply();
}

static void portal_toggle(void)
{
    if (s_screen_mode != SCREEN_MAIN && s_screen_mode != SCREEN_SETTINGS) {
        return;
    }
    if (wifi_portal_is_running()) {
        wifi_portal_stop();
        if (s_screen_mode == SCREEN_SETTINGS) {
            s_screen_mode = SCREEN_MAIN;
        }
        s_ui_dirty = true;
    } else if (wifi_portal_start(&s_settings, settings_saved, NULL) == ESP_OK) {
        s_screen_mode = SCREEN_SETTINGS;
        s_ui_dirty = true;
    } else {
        ESP_LOGW(TAG, "Settings AP start failed");
    }
}

static void buttons_init(void)
{
    gpio_config_t cfg = {
        .mode = GPIO_MODE_INPUT,
        .pin_bit_mask = (1ULL << PIN_BTN_PLUS) | (1ULL << PIN_BTN_MINUS) | (1ULL << PIN_BTN_UNIVERSAL),
        .pull_up_en = GPIO_PULLUP_ENABLE,
    };
    ESP_ERROR_CHECK(gpio_config(&cfg));
}
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
void app_main(void)
{
    ESP_LOGI(TAG, "Starting knitting assistant MVP firmware %s", APP_VERSION);

    esp_err_t nvs_err = nvs_flash_init();
    if (nvs_err == ESP_ERR_NVS_NO_FREE_PAGES || nvs_err == ESP_ERR_NVS_NEW_VERSION_FOUND) {
        ESP_ERROR_CHECK(nvs_flash_erase());
        nvs_err = nvs_flash_init();
    }
    ESP_ERROR_CHECK(nvs_err);
    session_restore_t restored_session;
    storage_load(&s_history, &s_settings, &restored_session);
    if (restored_session.active) {
        s_rows = restored_session.rows;
        s_accumulated_active_ms = restored_session.accumulated_active_ms;
        s_session_state = restored_session.state;
        s_session_started_ms = now_ms();
        s_active_started_ms = s_session_started_ms;
        ESP_LOGI(TAG, "Session restored rows=%d state=%d", s_rows, s_session_state);
    }

    power_latch_init();
    low_power_peripherals_init();
    buttons_init();
    adc_init_battery();

    ESP_ERROR_CHECK(lcd_init());
    ESP_ERROR_CHECK(lvgl_init_display());
    ui_create();
    s_boot_started_ms = now_ms();
    s_boot_until_ms = s_boot_started_ms + BOOT_ANIMATION_MS;
    s_last_activity_ms = s_boot_started_ms;
    backlight_apply();

    s_bat_percent = battery_percent_read();
    ui_update();

    xTaskCreate(app_task, "app_task", 6144, NULL, 5, NULL);
}

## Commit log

2026-06-19 Release v1.0
    [KA-001-3D - Base plate.step, KA-002-3D - Frontal case.step, KA-003-3D - Main button.step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]
2026-07-06 Add device settings portal feature docs
2026-07-07 Add 22 mm band hardware revision
    [KA-008-3D - Band holder V2 (for extrnal band).step, all_parts_universal_band.3mf]
